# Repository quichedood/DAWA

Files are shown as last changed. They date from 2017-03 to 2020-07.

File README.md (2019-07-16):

New version here : https://github.com/quichedood/DAWA-6.1

# DAWA - Data Acquisition With Arduino
French official website project : http://dawa.panik-po.com/
DAWA-V4

DAWA is an Arduino datalogger (and laptimer) shield for your motorbike.
It records 10 times per seconds in a CSV file lots of information.

# What information is logged ?
* __Raw data acquisition__ : On Triumph bikes and many others, ECU values can be directly read (I personnaly use : RPM, SPEED, GEAR POSITION, THROTTLE and BRAKE state)
* __Environement values__ : A 9-axis sensor (BNO055) is used to store G-forces and I hope soon, roll and pitch
* __Position values__ : A UBLOX 10Hz GPS chip gets realtime coordinates
* __Infrared temperatures__ : You can plug up to 4 infrared temperature sensors (tyres or ground t° for example)
* __Analog inputs__ : You can measure up to 6 analog inputs (suspension sensors for exemple)

# Where is it logged ?
Everything is stored on a micro SD card.  
10 times per seconds, a new line is created in a CSV file. This line contains every data values separated by a semicolon.  
Current values are displayed in realtime on the OLED screen attached.

# Could it be used as a laptimer ?
YES ! Since v4 and the integration of a 10Hz GPS chip, laptimer functions are available.

# How does it work ?
I couldn't make it easier !  
Press the button start recording, press again stop recording :)  
One CSV file is created on each new record.

# What about laptimer functions
A little bit more difficult, you have to put a file named "TRACKS.CSV" on the sdcard.  
This file will contain track name and finishline coordinates, one line per track :  
`<trackname>;<finishline lat. A>;<finishline lon. A>;<finishline lat. B>;<finishline lon. B>`  
`CAROLE;489799930;25224350;489800230;25226330`  
To keep precision, latitude and longitude should be converted to integers (multiply by 10 000 000).  
When start recording the closer track is automatically chosen.

# You said Bluetooth ?
Bluetooth connection is usefull in these 2 cases :
- You just finish your track session and want to know lap times / best lap
- Before using DAWA, some parameters could be adjusted, use the bluetooth console to setup them !

I'm using "Serial Bluetooth Terminal" on Androïd. Connect and type "help" to view all available commands

# What's next  
* __Laptimer split time__ : Add split time management

# Known bugs
* __Lean angle__ : Seems easy but in fact very complicated to obtain good values without drift

# Repository Contents
* /Arduino - The .ino file you need to put in the Arduino M0
* /Documentation - Some brief explanations about this shield (french - not translated)
* /Eagle Libraries - All Eagle parts I use in my schematics
* /Eagle Sources - Eagle files of this project
* /Gerber Sources - Last Gerber files, used to produce PCB
* /Partslist - A detailed BOM list

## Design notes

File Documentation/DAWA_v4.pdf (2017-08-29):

Pourquoi ce montage ?

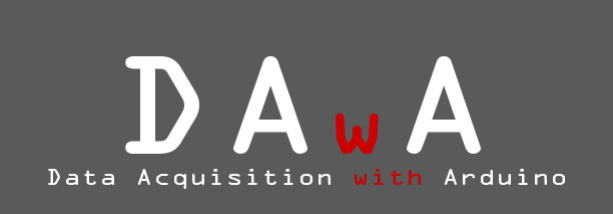
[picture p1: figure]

J’ai créé ce montage afin de pouvoir incruster dans mes vidéos différentes données comme par exemple le régime moteur ou encore l’inclinaison de la moto.

Certaines de ces informations peuvent être récupérées via des montages qui se branchent directement sur la prise OBD de la moto (prise diagnostic). L’implémentation est certes plus simple mais malheureusement sur nos motos, la version du protocole OBD utilisée est souvent ancienne et ne permet pas une lecture de plusieurs informations à une fréquence élevée. L’affichage est donc saccadé.

Pour ceux que ça intéresse, le très complet Freematics (http://freematics.com).

A qui est-il destiné ?

A tous les pistards équipés de motos Triumph. Ceux qui n’ont pas de Triumph mais qui sont intéressés, contactez-moi, on pourra étudier ça ensemble.

Comment ça marche ?

2 éléments font partis de ce projet :

- Un Arduino M0
C’est une carte électronique programmable que l’on trouve dans le commerce. C’est sur cette dernière que l’on trouve « l’intelligence » : le µprocesseur. Il peut être simplement programmé avec le code que je fournis via un câble USB relié au PC.
- Ma carte additionnelle
Cette carte additionnelle s'assemble avec l’Arduino M0, elle permet de faire l’interface avec la moto.

Quelles sont les données récupérées ?

Les données suivantes sont récupérées à une fréquence de 10Hz (10 fois par seconde) :
- Position de la poignée de gaz (de 0 à 100%)
- Activation de la poignée de frein (oui/non)
- Rapport engagé (N, 1, 2, 3, 4, 5, 6)
- Régime moteur (en tr/min)
- Inclinaison de la moto (tangage/roulis en degrés) – Problème de drift – code à corriger
- Température ambiante (en degrés)
- Coordonnées GPS de la moto
- Chronométrage (temps au tour)

Toutes ces données sont enregistrées sur la carte SD.

Comment ça se branche ?

2 branchements sont nécessaires :
- L’alimentation électrique, à brancher directement sur la batterie de la moto
- Le connecteur chargé de récupérer les données (5 fils) :
- Tr/min moteur (sur le calculateur)
- Vitesse moteur (sur le calculateur)
- Rapport engagé (sur le calculateur)
- Position de la poignée de gaz (sur le calculateur)
- Activation de la poignée de frein (sur le feu stop)

Comment l’utiliser ?

Très simplement, avant chaque session, un appui long sur le bouton permet d’activer l’enregistrement. Une fois la session terminée, un second appui long arrête l’enregistrement.

Le bouton est lumineux, son clignotement permet de s’assurer que l’enregistrement est bien en cours. Les données enregistrées sur la carte SD sont directement lisibles depuis un PC (fichier texte).

Le chronométrage fonctionne automatiquement du moment que les coordonnées GPS de la ligne d’arrivée du circuit sont saisis dans un fichier nommé « TRACKS.csv » présent à la racine de la carte SD. Le circuit le plus proche dans la liste sera automatiquement sélectionné.

Comment exploiter ces données ?

Différents logiciels existent sur le marché pour incruster des données sur une vidéo. Personnellement j’utilise Race Render (http://www.racerender.com).

Peut-on acheter ce montage tout fait ?

Je peux vous l’assembler oui, il faut compter environ 70€. (C’est +/- le prix de revient, je ne fais pas de marge) Cela comprend :
- Le montage DAWA (sans boitier)
- Un câble de 1m avec le bouton lumineux
- Un câble de 1m à relier sur les broches du calculateur
- L’antenne GPS
- L’Arduino M0

Soit à peu de choses près :

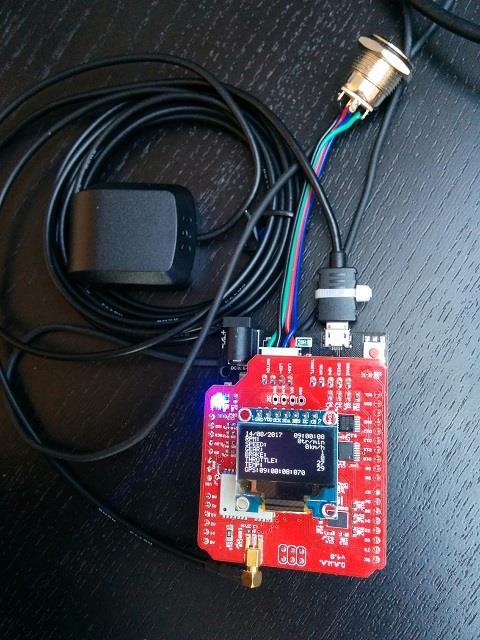
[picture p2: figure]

Il ne vous manquera plus qu’une carte micro SD et une pile plate CR1220

Des mises à jour sont prévues ?

Niveau matériel, je pense avoir enfin une version aboutie.
Un connecteur est tout de même présent au cas où l’on souhaite intégrer de nouveaux composants (protocole I2C).

Niveau programmation logiciel, c’est +/- sans limite donc pourquoi pas rajouter, comme certains me l’on demandé, des entrées pour les capteurs de position des suspensions ?

Néanmoins, la correction d’éventuels bugs est possible, il suffira de reprogrammer l’Arduino M0. Un PC et un câble USB vous suffiront !

Q&A

Q : J’ai déjà un Arduino M0, je peux l’utiliser ?
R : Bien sûr, rien de plus standard

Q : Est-ce que ce montage permet de me chronométrer ?
R : Oui depuis la version 4 ! Comparé à l’Alfano de référence les chronos sont pratiquement identiques. Les partiels ne sont pas gérés mais avec quelques lignes de code c’est largement faisable !

Q : Est-ce que ce montage fonctionne sur toutes les motos ?
R : Oui et non. Certaines motos (très) récentes commencent à utiliser des faisceaux multiplexés du coup impossible de récupérer chaque donnée sur un fil bien distinct. Généralisé dans l’automobile, BMW s’y essaie sur leurs motos pour les autres constructeurs j’ai un doute.
Sur les motos de marque autre que Triumph il faudra peut-être adapter quelques bricoles, à étudier. Néanmoins, la partie chronométrage ne s’appuie que sur la puce GPS donc fonctionnera sur toutes les motos.

Q : Est-ce garanti, y’a-t-il un support ?
R : Officiellement non, ça reste du « fait maison ». Après je réponds aux emails

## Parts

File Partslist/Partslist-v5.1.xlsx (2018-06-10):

Qty | Retailer | Value | Ref | Device | Package
1 | Mouser |  | CR1220 | 12mm 3V lithium coin cell
1 | Aliexpress |  |  | 12v connector
1 | Mouser |  | ADC128D818 | ADC | SOP65P640X120-16N
1 | Aliexpress |  |  | Arduino M0 (Robodyn)
1 | Aliexpress | 100pF |  | Capacitor | 0603
1 | Aliexpress | 10µF |  | Capacitor | 0603
1 | Aliexpress | 1µF |  | Capacitor | 0603
1 | Aliexpress | 4.7µF |  | Capacitor | 0603
2 | Aliexpress | 22pF |  | Capacitor | 0603
11 | Aliexpress | 0.1µF |  | Capacitor | 0603
1 | Mouser | 47pF | GRM1885C1H470JA01D | Capacitor | 0603
1 | Aliexpress |  | CD4050 | CMOS Hex Buffer/Converters | SOP65P640X120-16N
3 | Aliexpress |  | P82B96D | DUAL BIDIRECTIONAL BUS BUFFER | SOIC127P600X175-8N
1 | Aliexpress |  |  | GPS Antenna
1 | Aliexpress |  |  | GPS connector | MMCX STRAIGHT, EDGE MOUNT JACK- 50 OHM
1 | Aliexpress |  | UBLOX NEO-7M | GPS module
1 | Aliexpress |  |  | HM-11 (Bluetooth module) | JNHuaMao HM-11 Bluetooth 4.0 Transceiver
1 | Mouser | 27nH | LQG18HN27NJ00D | Inductor | 0603
2 | Aliexpress |  | MLX90614 ESF-BCC | Infrared temp. Sensor
1 | Mouser |  | BN055 | Intelligent 9-axis absolute orientation sensor | LGA-28_3.80X5.20/0.5
2 | Aliexpress |  |  | JST XH Connector (3 pins/F)
1 | Aliexpress |  |  | JST XH Connector (4 pins/F)
3 | Aliexpress |  |  | JST XH Connector (5 pins/F)
2 | Aliexpress |  |  | JST XH Connector (SMD/3 pins/M)
1 | Aliexpress |  |  | JST XH Connector (SMD/4 pins/M)
3 | Aliexpress |  |  | JST XH Connector (SMD/5 pins/M)
1 | Aliexpress |  |  | LED | 1206
1 | Aliexpress |  |  | Lithium coin cell 3v
1 | Aliexpress |  | DM3AT-SF-PEJM5 | Micro SD connector (SMD/push/push) | DM3AT-SF-PEJM5
1 | Aliexpress |  |  | OLED screen
2 | Mouser |  | TLV2374IPWR | OPERATIONAL AMPLIFIERS | SOP65P640X120-14N
1 | Mouser | 32.768kHz | CM7V-T1A | OSCILLATOR
1 | N/A |  |  | PCB
1 | Aliexpress |  |  | Pin header 1X32 (M)
1 | Mouser |  |  | Pin header 1X7 (F)
1 | Aliexpress |  |  | Pin header 2X3 (F)
1 | Aliexpress |  |  | Power button
1 | Mouser |  | CD40106BPW | QUADRUPLE LEVEL SHIFTER | SOP65P640X120-14N
1 | Aliexpress | 1kohm |  | Resistor | 0603
1 | Aliexpress | 200kohm |  | Resistor | 0603
1 | Aliexpress | 27kohm |  | Resistor | 0603
2 | Aliexpress | 220ohm |  | Resistor | 0603
8 | Aliexpress | 4.7kohm |  | Resistor | 0603
5 | Aliexpress | 10kohm |  | Resistor | 0603
1 | Mouser | 10ohm |  | Resistor | 1206
2 | Amazon |  |  | RJ45 (1m/2m)
3 | Aliexpress |  |  | RJ45 female socket
1 | Mouser |  | 24AA02E48 | Serial EEPROM | SOT23-5L
1 | Mouser |  | 74AHC1G125 | TRI-STATE SINGLE BUSS BUFFER | SOT23-5
1 | Mouser |  | PCA9306D | VOLTAGE-LEVEL TRANSLATOR | SOP50P310X90-8N
2 | Aliexpress |  |  | Wire cable (2m) - 4 cores
2 | Aliexpress |  |  | Wire cable (2m) - 5 cores

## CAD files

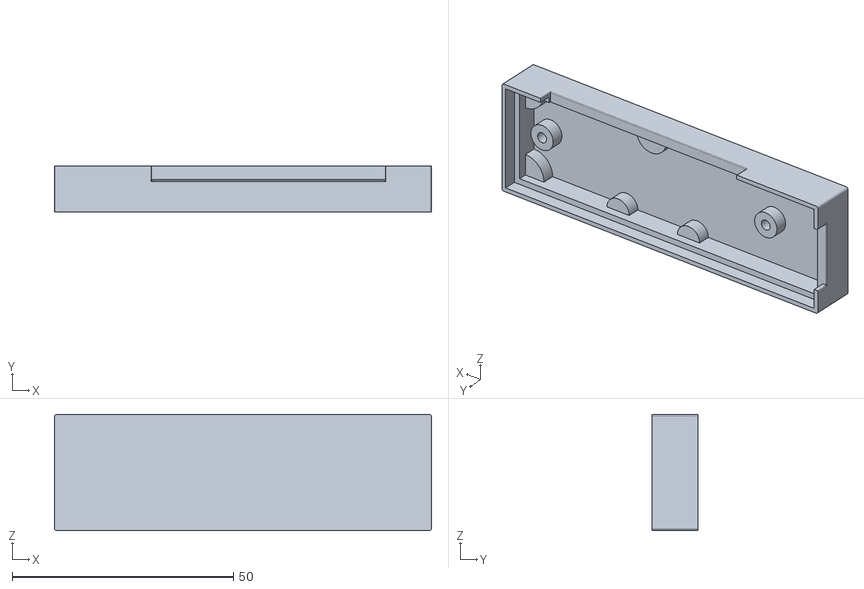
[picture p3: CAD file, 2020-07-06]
3D Case/MLX-SWITCH-PART1.stl
85.2 x 10.4 x 26.3

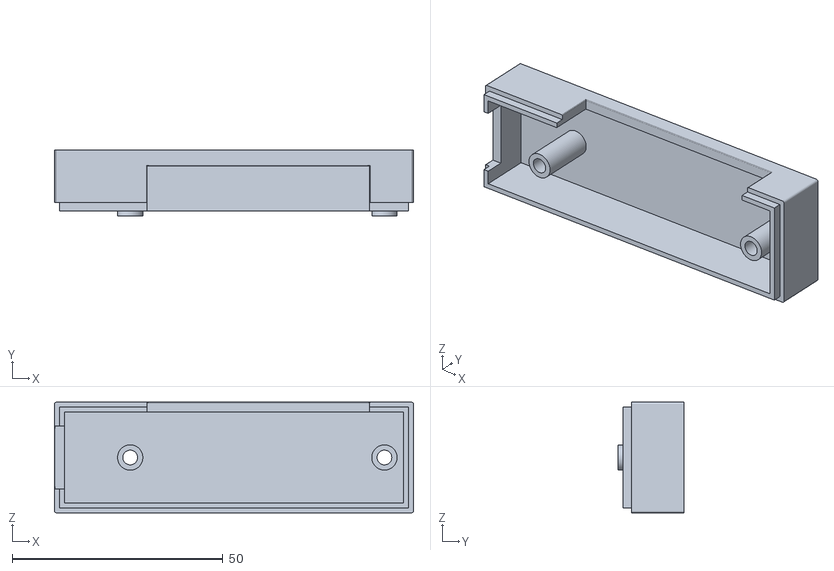
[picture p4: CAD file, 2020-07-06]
3D Case/MLX-SWITCH-PART2.stl
85.2 x 15.6 x 26.3

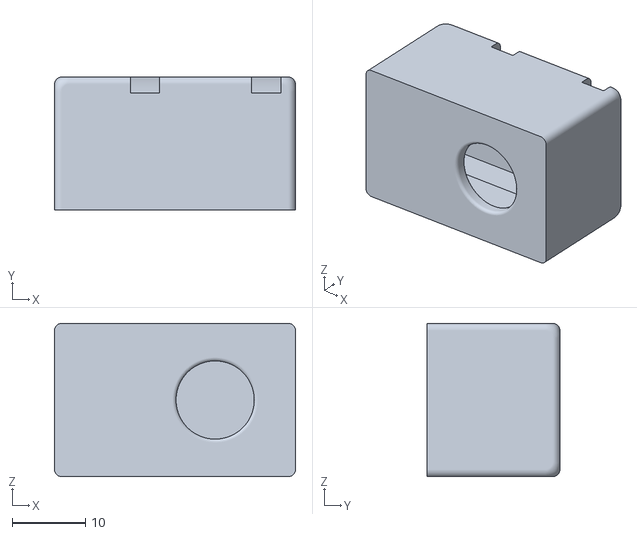
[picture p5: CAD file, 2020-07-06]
3D Case/MLX-PART1.stl
33.0 x 18.2 x 21.0

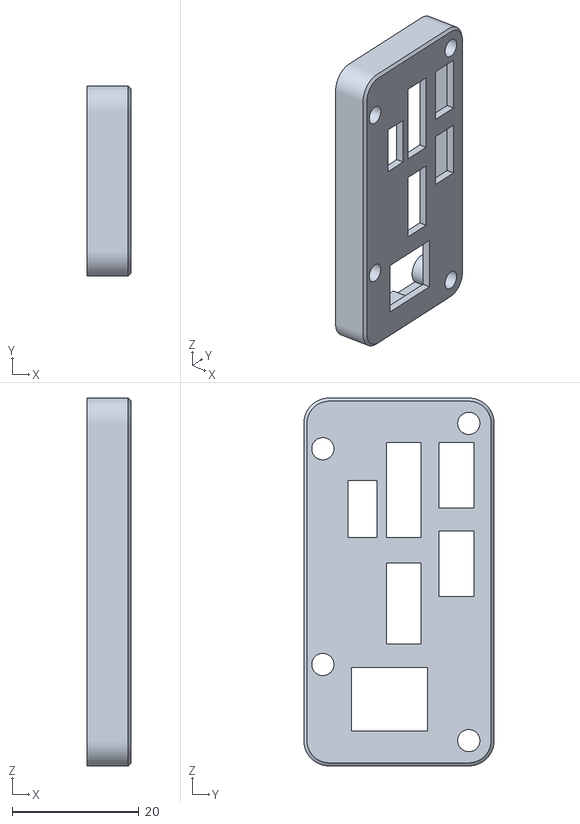
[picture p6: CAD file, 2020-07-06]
3D Case/DAWA-CASE-PART2.stl
7.00 x 30.0 x 58.0

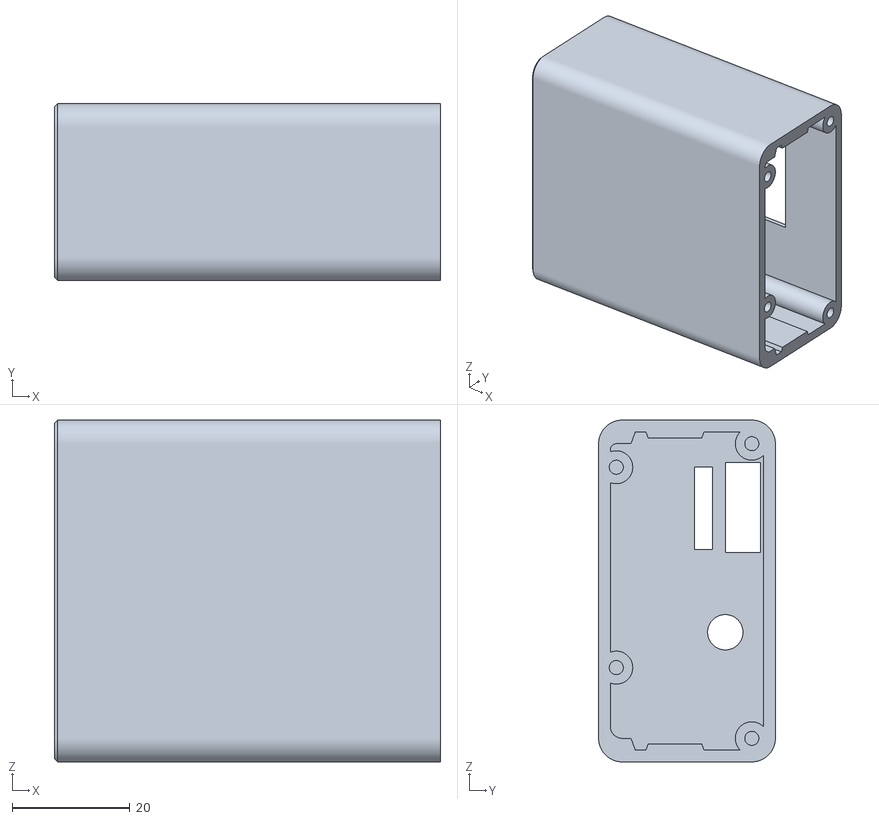
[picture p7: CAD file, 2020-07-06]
3D Case/DAWA-CASE-PART1.stl
65.5 x 30.0 x 58.0

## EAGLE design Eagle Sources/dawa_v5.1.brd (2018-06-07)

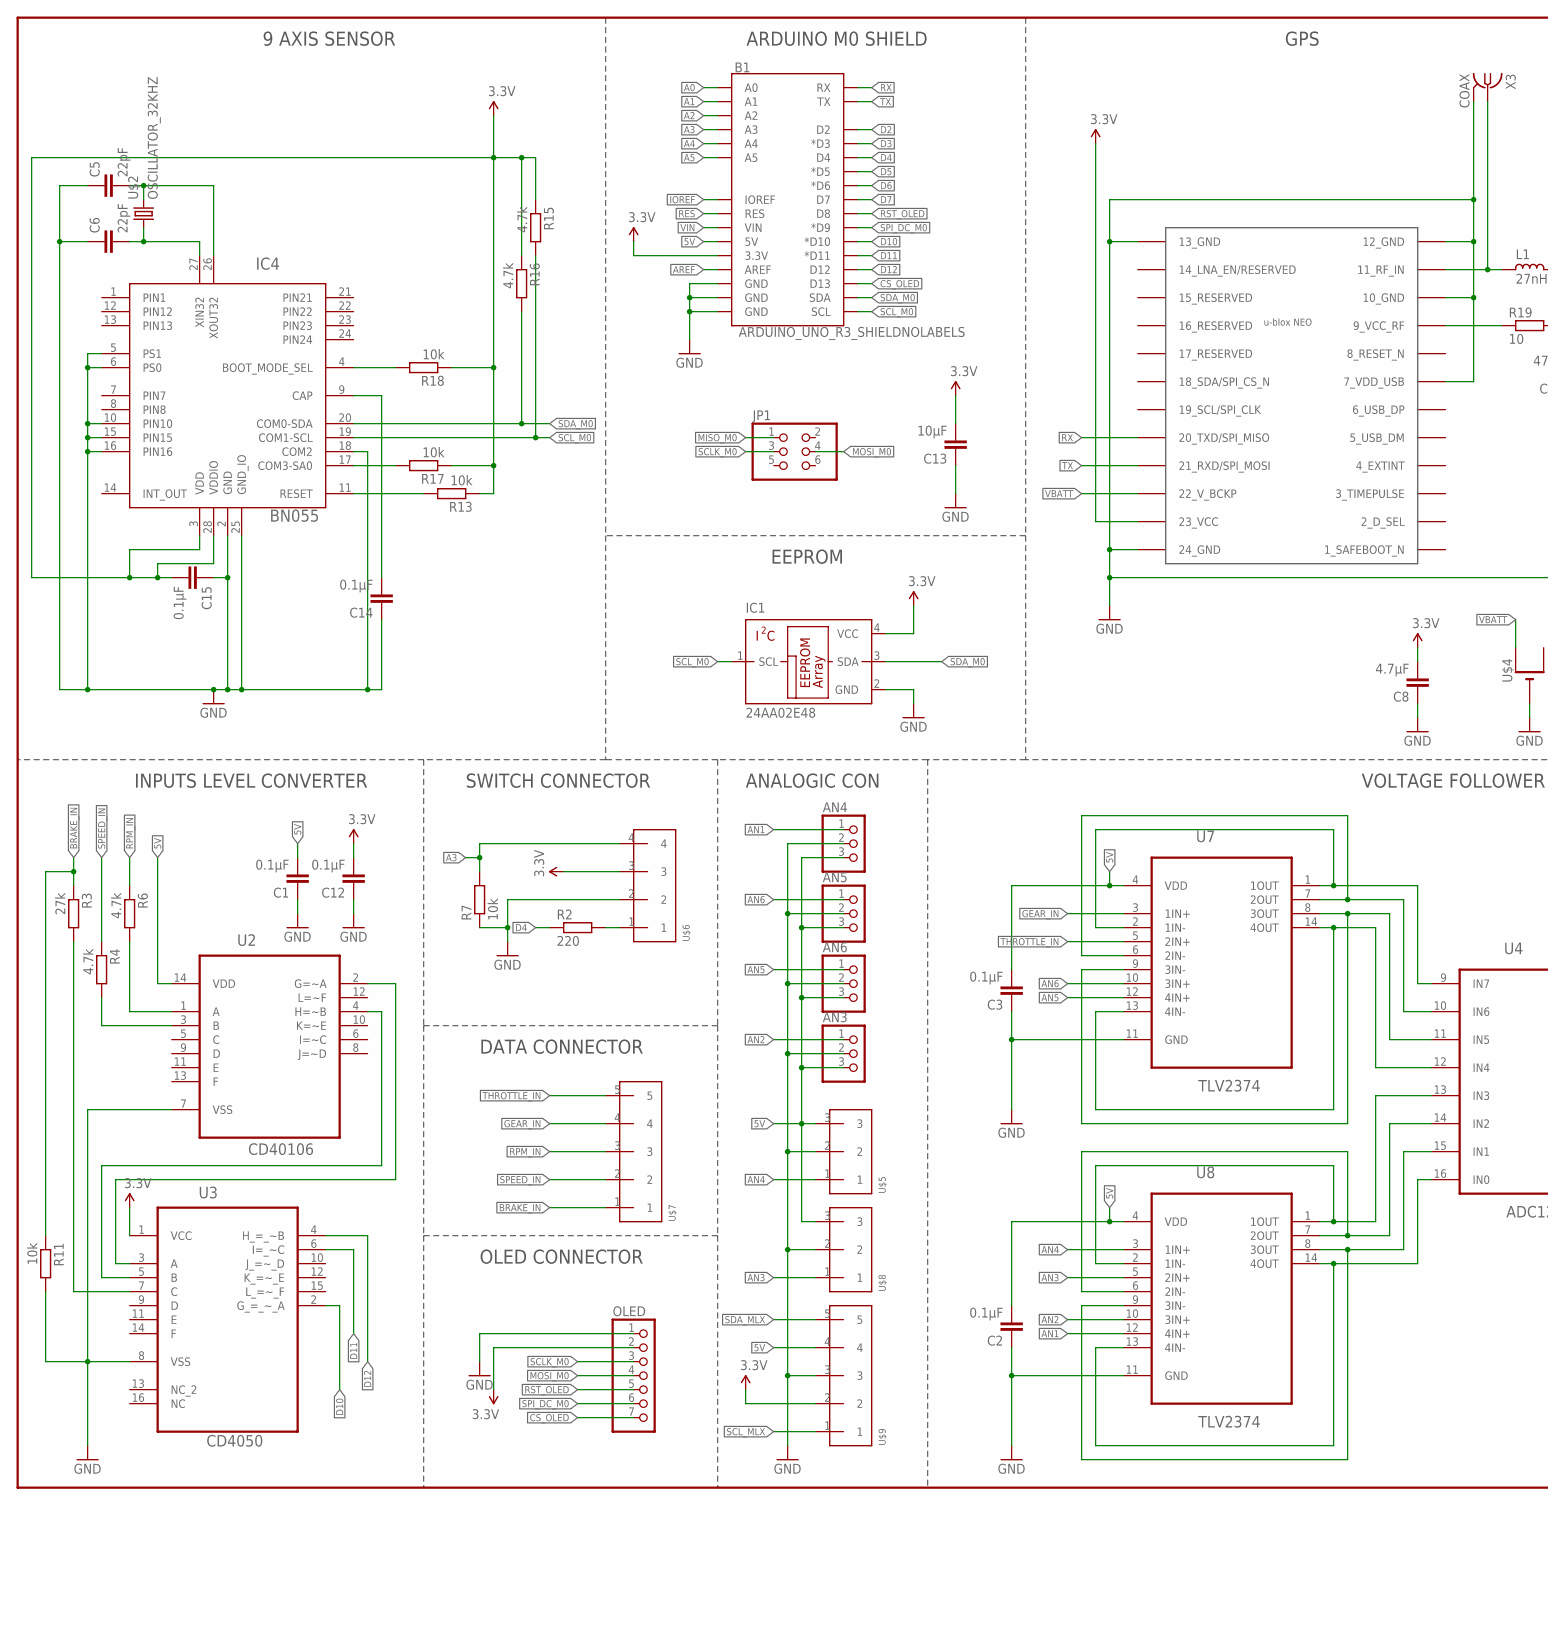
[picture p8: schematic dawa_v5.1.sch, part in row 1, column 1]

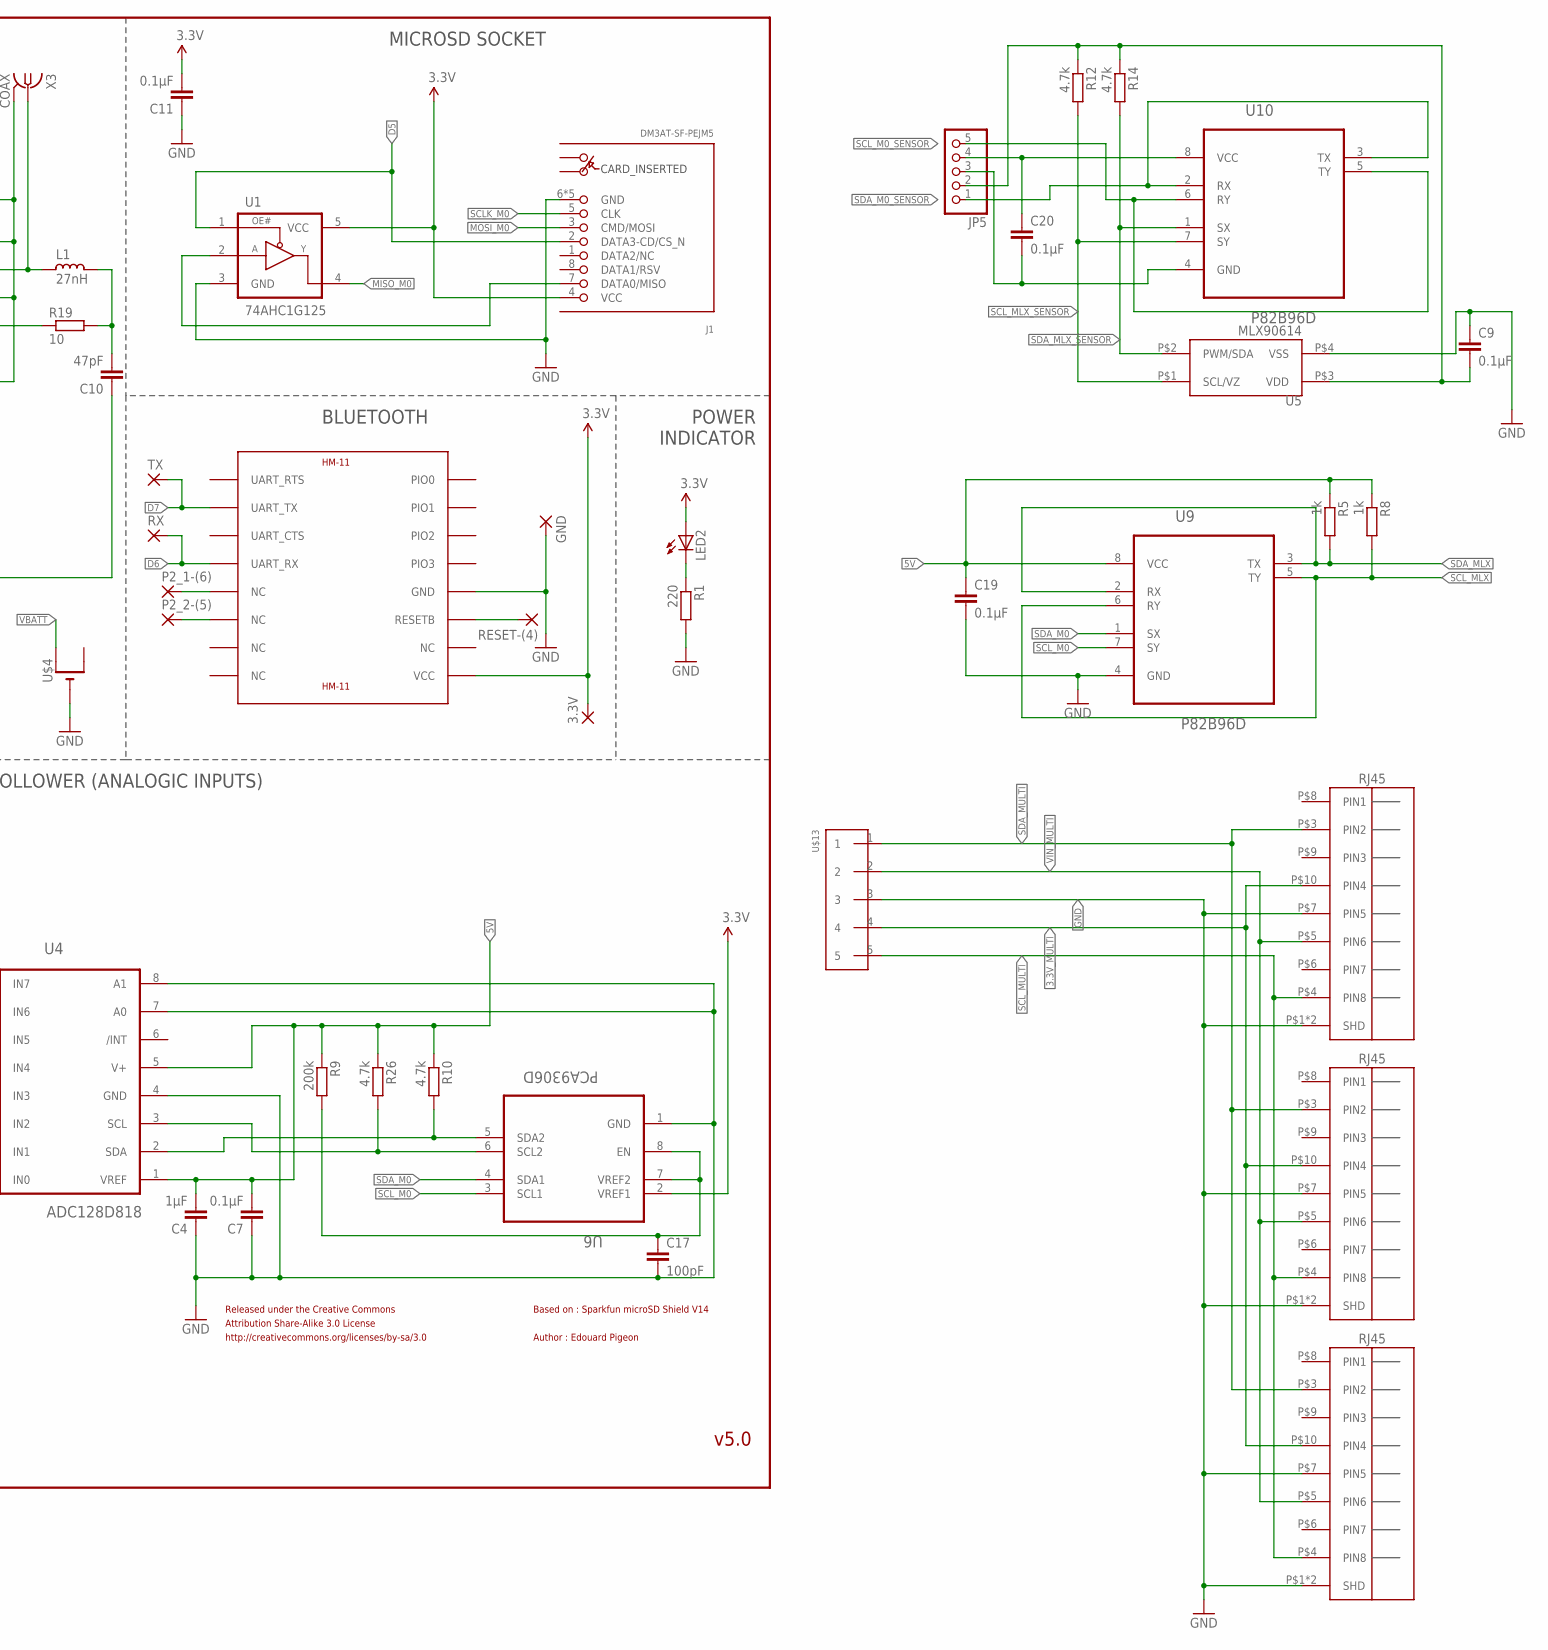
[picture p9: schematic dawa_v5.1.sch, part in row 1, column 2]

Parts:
3.3V: WIREPADSMD1,27-254; SMD1,27-2,54
AN3, AN4, AN5, AN6: PINHD-1X3; 1X03
B1: ARDUINO_UNO_R3_SHIELDNOLABELS; UNO_R3_SHIELD_NOLABELS
C1, C2, C3, C7, C9, C11, C12, C14, C15, C19, C20: 0.1µF; C0603
C4: 1µF; C0603
C5, C6: 22pF; C0603
C8: 4.7µF; C0603
C10: 47pF; C0603
C13: 10µF; C0603
C17: 100pF; C0603
GND: WIREPADSMD1,27-254; SMD1,27-2,54
IC1: 24AA02E48; SOT23-5L
IC4: BN055; LGA-28_3.80X5.20/0.5
J1: DM3AT-SF-PEJM5
JP1: PINHD-2X3; 2X03
JP5: PINHD-1X5; 1X05
L1: 27nH; L0603
LED2: LEDCHIPLED_1206; CHIPLED_1206
OLED: PINHD-1X7; 1X07
P2_1-(6), P2_2-(5): WIREPADSMD1,27-254; SMD1,27-2,54
R1, R2: 220; R0603
R3: 27k; R0603
R4, R6, R10, R12, R14, R15, R16, R26: 4.7k; R0603
R5, R8: 1k; R0603
R7, R11, R13, R17, R18: 10k; R0603
R9: 200k; R0603
R19: 10; M1206
RESET-(4): WIREPADSMD1,27-254; SMD1,27-2,54
RX: WIREPADSMD1,27-254; SMD1,27-2,54
TX: WIREPADSMD1,27-254; SMD1,27-2,54
U1: 74AHC1G125; SOT23-5
U2: CD40106; SOP65P640X120-14N
U3: CD4050; SOP65P640X120-16N
U4: ADC128D818; SOP65P640X120-16N
U5: MLX90614; TO-39
U6: PCA9306D; SOP50P310X90-8N
U7, U8: TLV2374; SOP65P640X120-14N
U9, U10: P82B96D; SOIC127P600X175-8N
U$1: HM-11
U$2: OSCILLATOR_32KHZ; OSCILLATOR_SMD
U$3: NEO-M8
U$4: CR1220SMT; CR1220-SMD
U$5, U$8: 3_PIN_JST-XH-SMD
U$6: 4_PIN_JST-XH-SMD
U$7, U$9, U$13: 5_PIN_JST-XH-SMD
U$10, U$11, U$12: RJ45
X3: COAX; MMCX-J-P-X-ST-EM1-MKT

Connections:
3.3V: 3.3V.1, B1.3.3V, C8.2, C11.2, C12.2, C13.2, C15.2, IC1.4 (VCC), IC4.3 (VDD), IC4.28 (VDDIO), J1.4 (VCC), LED2.A, OLED.2, R13.1, R15.1, R16.1, R17.1, R18.1, U1.5 (VCC), U3.1 (VCC), U6.2 (VREF1), U$1.VCC, U$3.23 (23_VCC), U$6.3, U$9.2
3.3V_MULTI: U$10.P$10 (PIN4), U$11.P$10 (PIN4), U$12.P$10 (PIN4), U$13.4
5V: AN3.3, AN4.3, AN5.3, AN6.3, B1.5V, C1.2, C2.2, C3.2, C4.2, C7.2, C19.1, R5.1, R8.1, R9.1, R10.1, R26.1, U2.14 (VDD), U4.1 (VREF), U4.5 (V+), U7.4 (VDD), U8.4 (VDD), U9.8 (VCC), U$5.3, U$8.3, U$9.4
A0: B1.A0
A1: B1.A1
A2: B1.A2
A3: B1.A3, R7.2, U$6.4
A4: B1.A4
A5: B1.A5
AN1: AN4.1, U8.12 (4IN+)
AN2: AN3.1, U8.10 (3IN+)
AN3: U8.5 (2IN+), U$8.1
AN4: U8.3 (1IN+), U$5.1
AN5: AN6.1, U7.12 (4IN+)
AN6: AN5.1, U7.10 (3IN+)
AREF: B1.AREF
BRAKE_IN: R3.1, R11.1, U$7.1
CS_OLED: B1.D13, OLED.7
D2: B1.D2
D3: B1.D3 (*D3)
D4: B1.D4, R2.1
D5: B1.D5 (*D5), J1.2 (DATA3-CD/CS_N), U1.1 (OE#)
D6: B1.D6 (*D6), RX.1, U$1.UART_RX
D7: B1.D7, TX.1, U$1.UART_TX
D10: B1.D10 (*D10), U3.2 (G_=_~_A)
D11: B1.D11 (*D11), U3.6 (I=_~C)
D12: B1.D12, U3.4 (H_=_~B)
GEAR_IN: U7.3 (1IN+), U$7.4
GND: AN3.2, AN4.2, AN5.2, AN6.2, B1.GND@0 (GND), B1.GND@1 (GND), B1.GND@2 (GND), C1.1, C2.1, C3.1, C4.1, C5.1, C6.1, C7.1, C8.1, C9.1, C10.1, C11.1, C12.1, C13.1, C14.1, C15.1, C17.2, C19.2, GND.1, IC1.2 (GND), IC4.2 (GND), IC4.5 (PS1), IC4.6 (PS0), IC4.10 (PIN10), IC4.15 (PIN15), IC4.16 (PIN16), IC4.18 (COM2), IC4.25 (GND_IO), J1.6 (GND), J1.MOUNT0 (GND), J1.MOUNT1 (GND), J1.MOUNT2 (GND), J1.MOUNT3 (GND), OLED.1, R1.2, R7.1, R11.2, U1.3 (GND), U2.7 (VSS), U3.8 (VSS), U4.4 (GND), U4.7 (A0), U4.8 (A1), U5.P$4 (VSS), U6.1 (GND), U7.11 (GND), U8.11 (GND), U9.4 (GND), U$1.GND, U$3.7 (7_VDD_USB), U$3.10 (10_GND), U$3.12 (12_GND), U$3.13 (13_GND), U$3.24 (24_GND), U$4.-, U$5.2, U$6.2, U$8.2, U$9.3, U$10.P$1 (SHD), U$10.P$2 (SHD), U$10.P$7 (PIN5), U$11.P$1 (SHD), U$11.P$2 (SHD), U$11.P$7 (PIN5), U$12.P$1 (SHD), U$12.P$2 (SHD), U$12.P$7 (PIN5), U$13.3, X3.2@1 (GND), X3.2@2 (GND), X3.2@3 (GND), X3.2@4 (GND)
IOREF: B1.IOREF
MISO_M0: JP1.1, U1.4 (Y)
MOSI_M0: J1.3 (CMD/MOSI), JP1.4, OLED.4
unnamed: R2.2, U$6.1
unnamed: R6.2, U2.1 (A)
unnamed: U2.2 (G=~A), U3.3 (A)
unnamed: R4.2, U2.3 (B)
unnamed: R3.2, U3.7 (C)
unnamed: LED2.C, R1.1
unnamed: IC4.11 (RESET), R13.2
unnamed: P2_1-(6).1, U$1.NC@5 (NC)
unnamed: RESET-(4).1, U$1.RESETB
unnamed: J1.7 (DATA0/MISO), U1.2 (A)
unnamed: C10.2, L1.1, R19.2
unnamed: U4.13 (IN3), U8.1 (1OUT), U8.2 (1IN-)
unnamed: C14.2, IC4.9 (CAP)
unnamed: IC4.4 (BOOT_MODE_SEL), R18.2
unnamed: C5.2, IC4.26 (XOUT32), U$2.2
unnamed: C6.2, IC4.27 (XIN32), U$2.1
unnamed: IC4.17 (COM3-SA0), R17.2
unnamed: P2_2-(5).1, U$1.NC@6 (NC)
unnamed: R19.1, U$3.9 (9_VCC_RF)
unnamed: L1.2, U$3.11 (11_RF_IN), X3.1
unnamed: U2.4 (H=~B), U3.5 (B)
unnamed: R26.2, U4.3 (SCL), U6.6 (SCL2)
unnamed: R10.2, U4.2 (SDA), U6.5 (SDA2)
unnamed: U4.9 (IN7), U7.1 (1OUT), U7.2 (1IN-)
unnamed: U4.10 (IN6), U7.6 (2IN-), U7.7 (2OUT)
unnamed: U4.11 (IN5), U7.8 (3OUT), U7.9 (3IN-)
unnamed: U4.12 (IN4), U7.13 (4IN-), U7.14 (4OUT)
unnamed: C17.1, R9.2, U6.7 (VREF2), U6.8 (EN)
unnamed: U4.14 (IN2), U8.6 (2IN-), U8.7 (2OUT)
unnamed: U4.15 (IN1), U8.8 (3OUT), U8.9 (3IN-)
unnamed: U4.16 (IN0), U8.13 (4IN-), U8.14 (4OUT)
unnamed: C20.1, JP5.4, U10.8 (VCC)
unnamed: C9.2, JP5.2, R12.1, R14.1, U5.P$3 (VDD)
unnamed: C20.2, JP5.3, U10.4 (GND)
RES: B1.RES
RPM_IN: R6.1, U$7.3
RST_OLED: B1.D8, OLED.5
RX: B1.RX, U$3.20 (20_TXD/SPI_MISO)
SCLK_M0: J1.5 (CLK), JP1.3, OLED.3
SCL_M0: B1.SCL, IC1.1 (SCL), IC4.19 (COM1-SCL), R15.2, U6.3 (SCL1), U9.7 (SY)
SCL_M0_SENSOR: JP5.5, U10.5 (TY), U10.6 (RY)
SCL_MLX: R8.2, U9.5 (TY), U9.6 (RY), U$9.1
SCL_MLX_SENSOR: R12.2, U5.P$1 (SCL/VZ), U10.7 (SY)
SCL_MULTI: U$10.P$4 (PIN8), U$11.P$4 (PIN8), U$12.P$4 (PIN8), U$13.5
SDA_M0: B1.SDA, IC1.3 (SDA), IC4.20 (COM0-SDA), R16.2, U6.4 (SDA1), U9.1 (SX)
SDA_M0_SENSOR: JP5.1, U10.2 (RX), U10.3 (TX)
SDA_MLX: R5.2, U9.2 (RX), U9.3 (TX), U$9.5
SDA_MLX_SENSOR: R14.2, U5.P$2 (PWM/SDA), U10.1 (SX)
SDA_MULTI: U$10.P$3 (PIN2), U$11.P$3 (PIN2), U$12.P$3 (PIN2), U$13.1
SPEED_IN: R4.1, U$7.2
SPI_DC_M0: B1.D9 (*D9), OLED.6
THROTTLE_IN: U7.5 (2IN+), U$7.5
TX: B1.TX, U$3.21 (21_RXD/SPI_MOSI)
VBATT: U$3.22 (22_V_BCKP), U$4.+$1 (+)
VIN: B1.VIN
VIN_MULTI: U$10.P$5 (PIN6), U$11.P$5 (PIN6), U$12.P$5 (PIN6), U$13.2

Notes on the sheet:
POWER INDICATOR
Released under the Creative Commons
v5.0
VOLTAGE FOLLOWER (ANALOGIC INPUTS)
MICROSD SOCKET
ARDUINO M0 SHIELD
BLUETOOTH
Attribution Share-Alike 3.0 License
http://creativecommons.org/licenses/by-sa/3.0
Based on : Sparkfun microSD Shield V14
Author : Edouard Pigeon
9 AXIS SENSOR
INPUTS LEVEL CONVERTER
OLED CONNECTOR
DATA CONNECTOR
EEPROM
SWITCH CONNECTOR
GPS
ANALOGIC CON

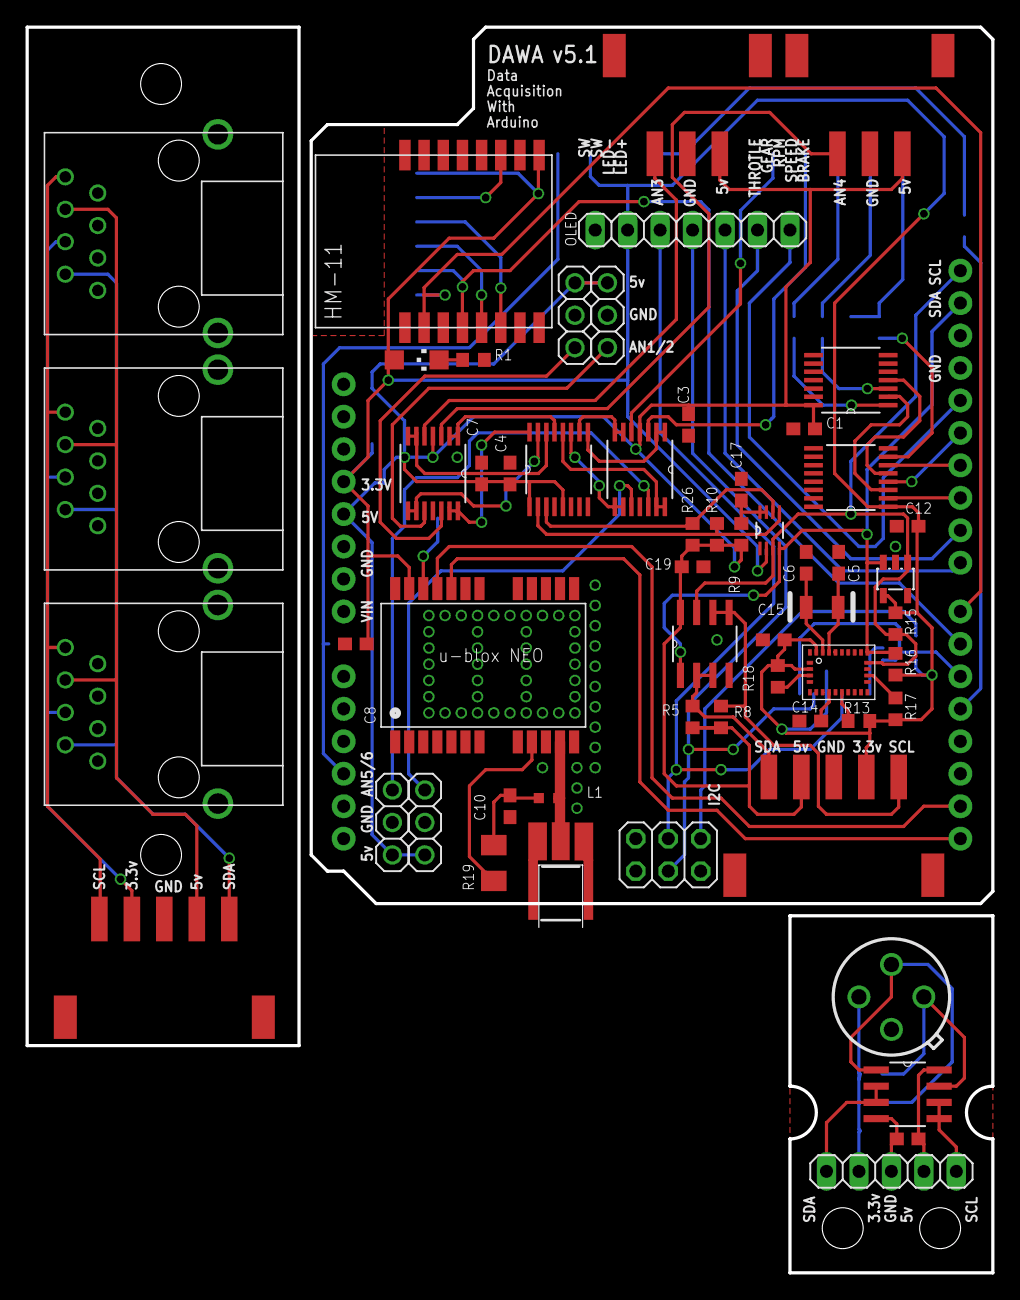
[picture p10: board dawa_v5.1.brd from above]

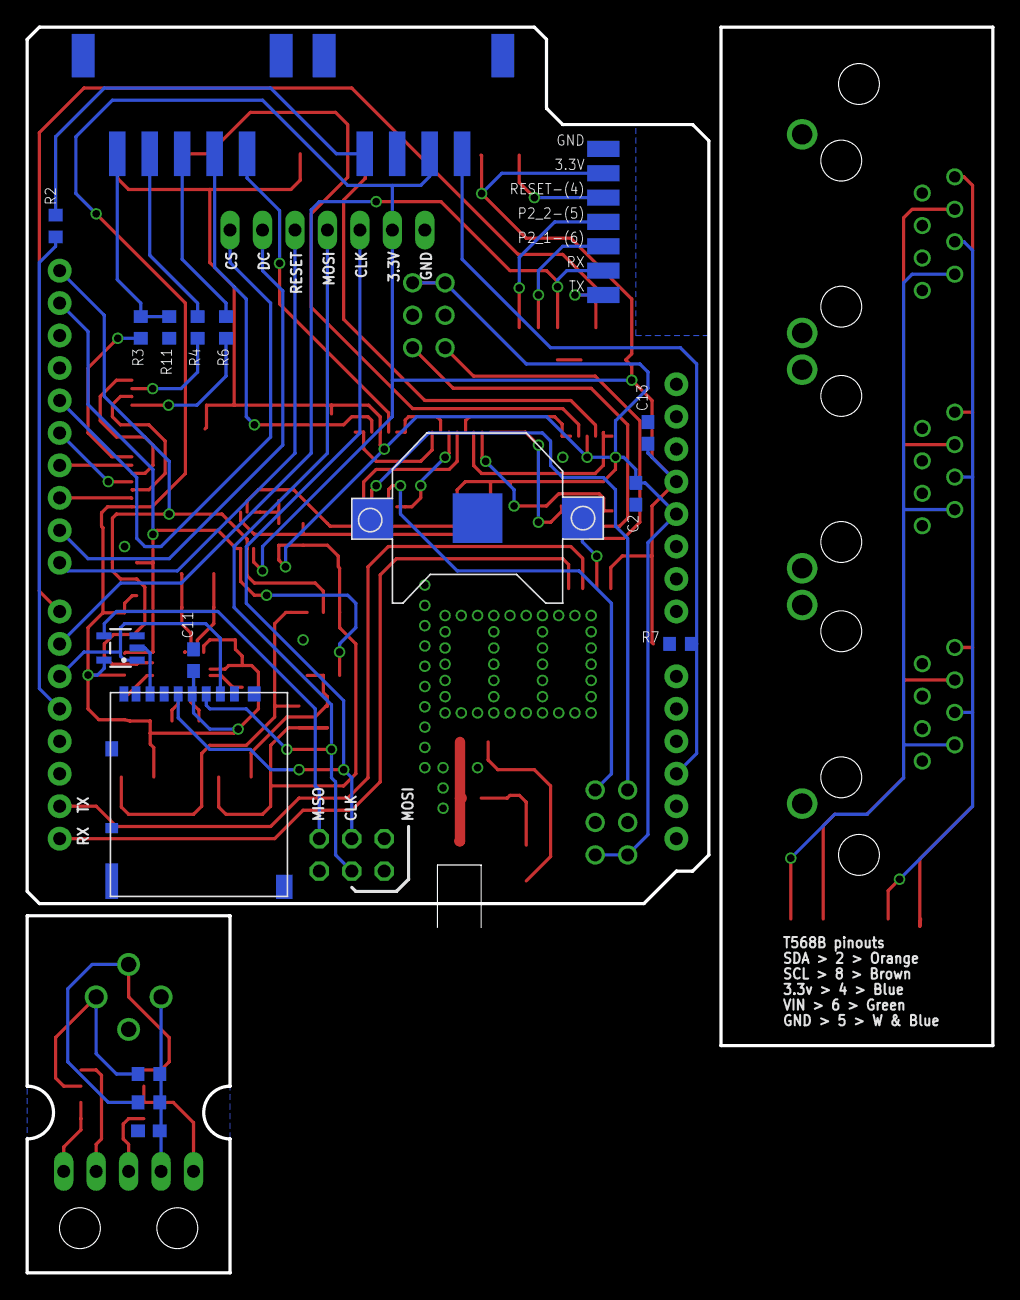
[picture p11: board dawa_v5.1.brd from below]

Board: 2 copper layers, 75.6 x 97.5 mm, 82 parts (24 on the bottom side), 77 nets.

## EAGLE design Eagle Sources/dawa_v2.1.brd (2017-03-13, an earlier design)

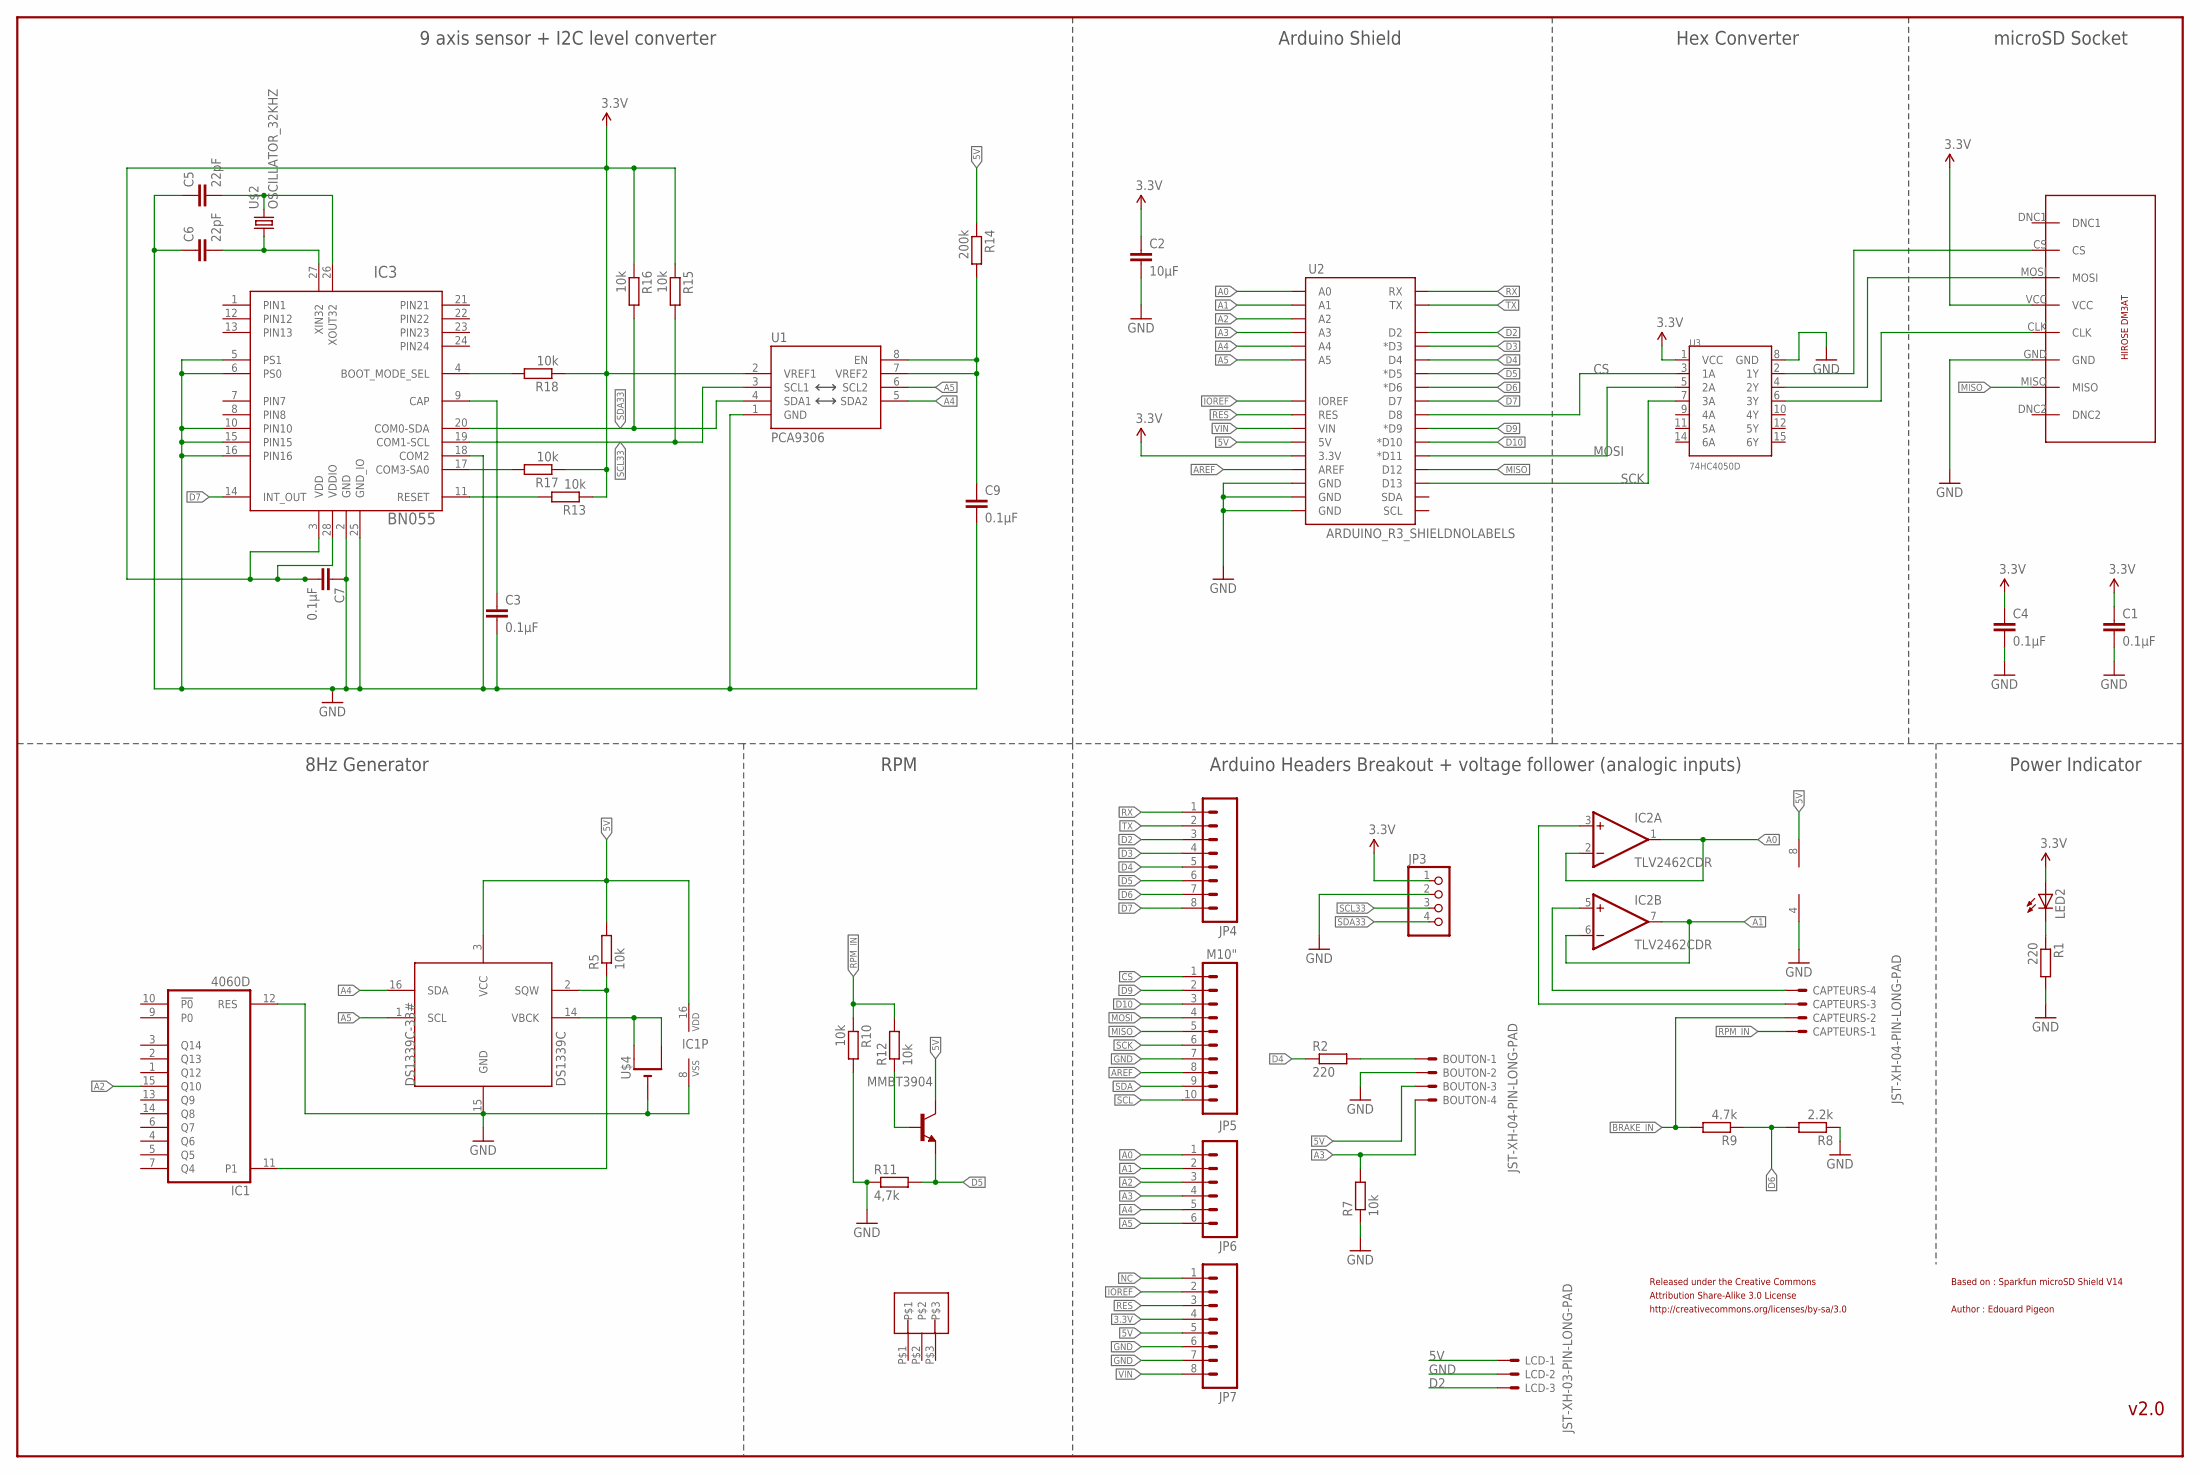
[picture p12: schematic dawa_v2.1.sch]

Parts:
BOUTON: JST-XH-04-PIN-LONG-PAD; JST-XH-04-PACKAGE-LONG-PAD
C1, C3, C4, C7, C9: 0.1µF; C1206
C2: 10µF; C1206
C5, C6: 22pF; C1206
CAPTEURS: JST-XH-04-PIN-LONG-PAD; JST-XH-04-PACKAGE-LONG-PAD
DS1339C-33#: DS1339C
IC1: 4060D; SO16
IC2: TLV2462CDR; SO08
IC3: BN055; LGA-28_3.80X5.20/0.5
JP3: PINHD-1X4; 1X04
JP4: M08; 1X08
JP5: M10"; 1X10
JP6: M06SIP; 1X06
JP7: M081X08; 1X08
LCD: JST-XH-03-PIN-LONG-PAD; JST-XH-03-PACKAGE-LONG-PAD
LED2: LEDCHIPLED_1206; CHIPLED_1206
MMBT3904: MMBT3904LT1-NPN-SOT23-BEC; SOT23-BEC
R1, R2: 220; M1206
R5, R7, R10, R12, R13, R15, R16, R17, R18: 10k; M1206
R8: 2.2k; M1206
R9: 4.7k; M1206
R11: 4,7k; M1206
R14: 200k; M1206
U1: PCA9306; PSOP-8
U2: ARDUINO_R3_SHIELDNOLABELS; UNO_R3_SHIELD_NOLABELS
U3: 74HC4050D; SO016
U$2: OSCILLATOR_32KHZ; OSCILLATOR_SMD
U$3: 3_PIN_JST-XH
U$4: CR1220SMT; CR1220-SMD
U$5: DM3AT

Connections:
3.3V: C1.1, C2.1, C4.1, C7.2, IC3.3 (VDD), IC3.28 (VDDIO), JP3.1, JP7.4, LED2.A, R13.1, R15.1, R16.1, R17.1, R18.1, U1.2 (VREF1), U2.3.3V, U3.1 (VCC), U$5.VCC
5V: BOUTON.3, DS1339C-33#.3 (VCC), IC1.16 (VDD), IC2.8 (V+), JP7.5, LCD.1, MMBT3904.C, R5.2, R14.1, U2.5V
A0: IC2.1 (OUT), IC2.2 (-IN), JP6.1, U2.A0
A1: IC2.6 (-IN), IC2.7 (OUT), JP6.2, U2.A1
A2: IC1.15 (Q10), JP6.3, U2.A2
A3: BOUTON.4, JP6.4, R7.2, U2.A3
A4: DS1339C-33#.16 (SDA), JP6.5, U1.5 (SDA2), U2.A4
A5: DS1339C-33#.1 (SCL), JP6.6, U1.6 (SCL2), U2.A5
AREF: JP5.8, U2.AREF
BRAKE_IN: CAPTEURS.2, R9.2
CS: JP5.1, U2.D8, U3.3 (1A)
D2: JP4.3, LCD.3, U2.D2
D3: JP4.4, U2.D3 (*D3)
D4: JP4.5, R2.1, U2.D4
D5: JP4.6, MMBT3904.E, R11.2, U2.D5 (*D5)
D6: JP4.7, R8.2, R9.1, U2.D6 (*D6)
D7: IC3.14 (INT_OUT), JP4.8, U2.D7
D9: JP5.2, U2.D9 (*D9)
D10: JP5.3, U2.D10 (*D10)
GND: BOUTON.2, C1.2, C2.2, C3.2, C4.2, C5.1, C6.1, C7.1, C9.2, DS1339C-33#.15 (GND), IC1.8 (VSS), IC1.12 (RES), IC2.4 (V-), IC3.2 (GND), IC3.5 (PS1), IC3.6 (PS0), IC3.10 (PIN10), IC3.15 (PIN15), IC3.16 (PIN16), IC3.18 (COM2), IC3.25 (GND_IO), JP3.2, JP5.7, JP7.6, JP7.7, LCD.2, R1.2, R7.1, R8.1, R10.2, R11.1, U1.1 (GND), U2.GND@0 (GND), U2.GND@1 (GND), U2.GND@2 (GND), U3.8 (GND), U$4.-, U$5.GND
IOREF: JP7.2, U2.IOREF
MISO: JP5.5, U2.D12, U$5.MISO
MOSI: JP5.4, U2.D11 (*D11), U3.5 (2A)
unnamed: BOUTON.1, R2.2
unnamed: U3.4 (2Y), U$5.MOSI
unnamed: DS1339C-33#.14 (VBCK), U$4.+$1 (+), U$4.+$2 (+1)
unnamed: U3.6 (3Y), U$5.CLK
unnamed: LED2.C, R1.1
unnamed: IC3.11 (RESET), R13.2
unnamed: CAPTEURS.4, IC2.5 (+IN)
unnamed: CAPTEURS.3, IC2.3 (+IN)
unnamed: C9.1, R14.2, U1.7 (VREF2), U1.8 (EN)
unnamed: C3.1, IC3.9 (CAP)
unnamed: IC3.4 (BOOT_MODE_SEL), R18.2
unnamed: C5.2, IC3.26 (XOUT32), U$2.2
unnamed: C6.2, IC3.27 (XIN32), U$2.1
unnamed: IC3.17 (COM3-SA0), R17.2
unnamed: DS1339C-33#.2 (SQW), IC1.11 (P1), R5.1
unnamed: MMBT3904.B, R12.1
unnamed: U3.2 (1Y), U$5.CS
NC: JP7.1
RES: JP7.3, U2.RES
RPM_IN: CAPTEURS.1, R10.1, R12.2
RX: JP4.1, U2.RX
SCK: JP5.6, U2.D13, U3.7 (3A)
SCL: JP5.10
SCL33: IC3.19 (COM1-SCL), JP3.3, R15.2, U1.3 (SCL1)
SDA: JP5.9
SDA33: IC3.20 (COM0-SDA), JP3.4, R16.2, U1.4 (SDA1)
TX: JP4.2, U2.TX
VIN: JP7.8, U2.VIN

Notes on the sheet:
Power Indicator
Released under the Creative Commons
v2.0
Arduino Headers Breakout + voltage follower (analogic inputs)
microSD Socket
Hex Converter
Arduino Shield
8Hz Generator
RPM
Attribution Share-Alike 3.0 License
http://creativecommons.org/licenses/by-sa/3.0
Based on : Sparkfun microSD Shield V14
Author : Edouard Pigeon
9 axis sensor + I2C level converter

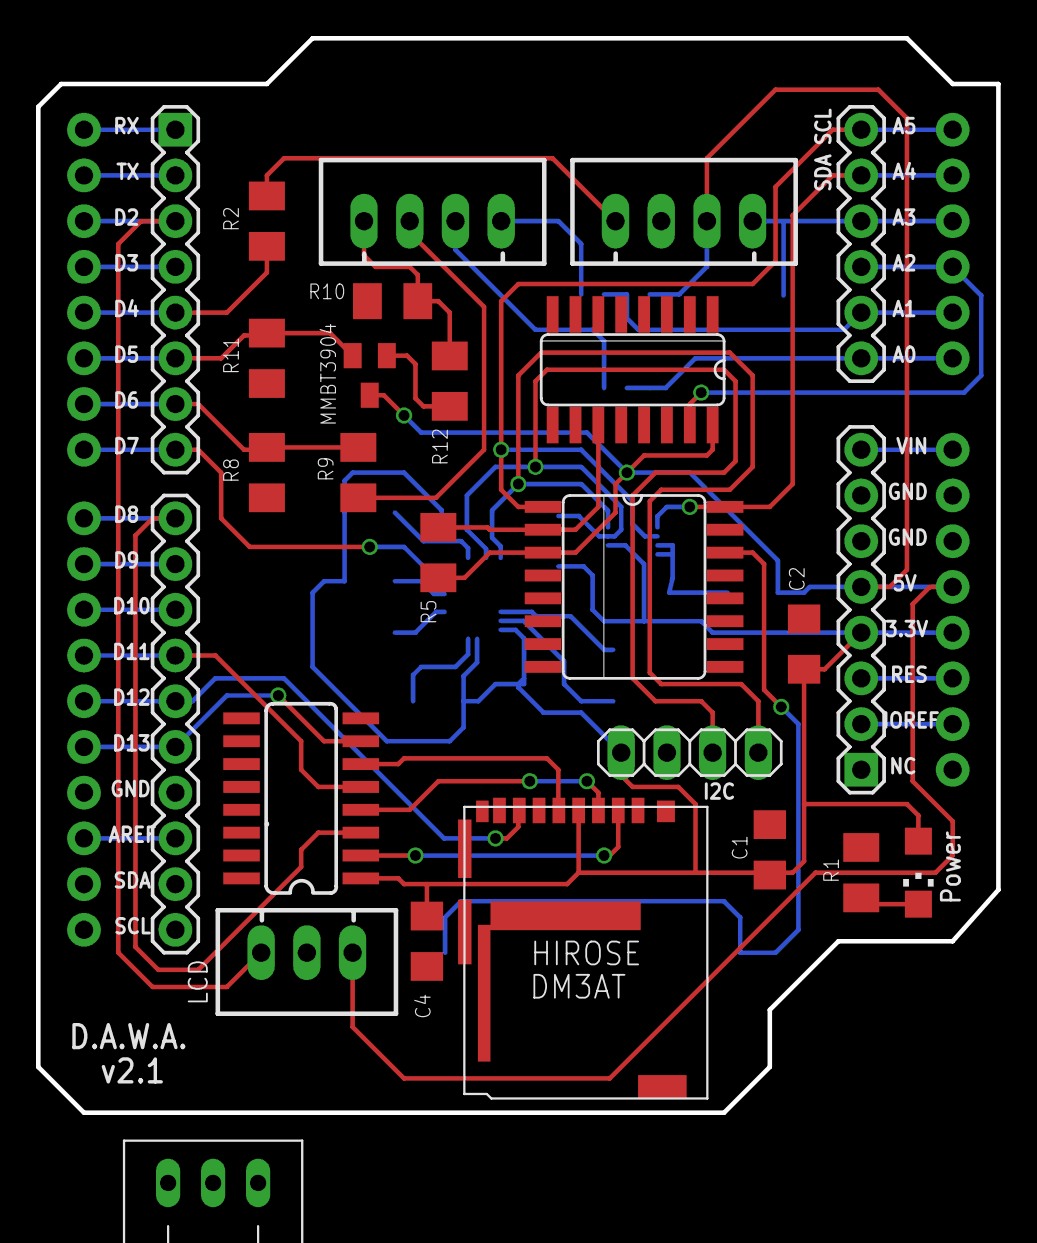
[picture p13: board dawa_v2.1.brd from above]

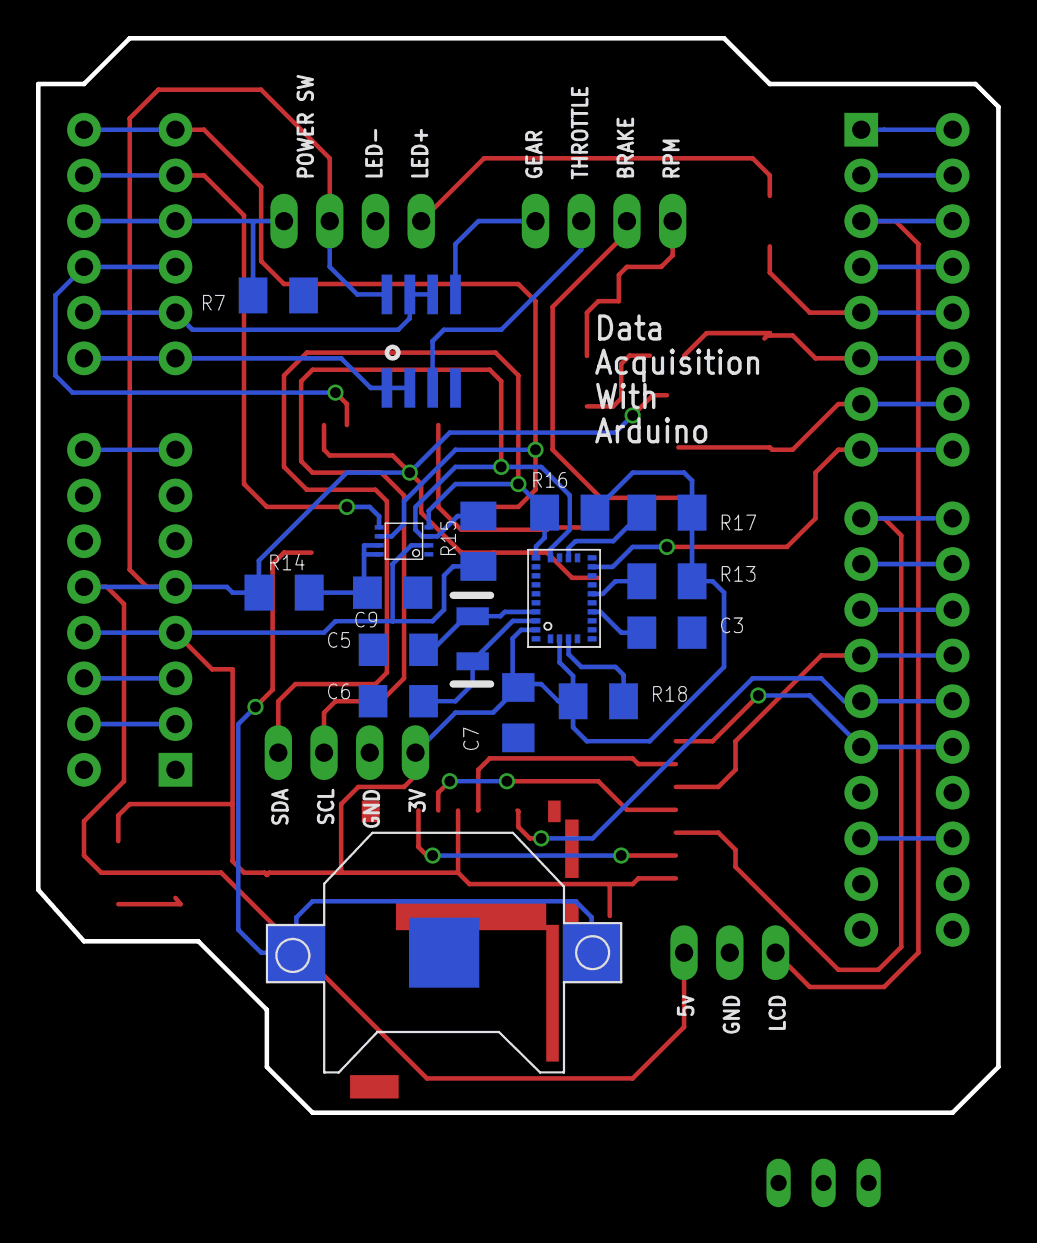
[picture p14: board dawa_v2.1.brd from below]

Board: 2 copper layers, 53.3 x 59.7 mm, 44 parts (17 on the bottom side), 48 nets.

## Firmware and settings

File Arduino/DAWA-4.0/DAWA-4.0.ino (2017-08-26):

/*
   DAWA 4.0 (Arduino M0)
   Triumph motorbikes laptimer/datalogger
   Edouard PIGEON - 2017
*/

// Librairies
#include <SPI.h>

/*
   NeoGPS library
   https://github.com/SlashDevin/NeoGPS
*/
#include <NMEAGPS.h>
HardwareSerial & gps_port = Serial5;
#define DEBUG_PORT SERIAL_PORT_USBVIRTUAL // Debug to USB serial console
static NMEAGPS  gps;
static gps_fix  fix_data;
static gps_fix  fix_data_prev;

/*
   thomasfredericks/Bounce2 library
   https://github.com/thomasfredericks/Bounce2
*/
#include <Bounce2.h>
Bounce debouncer = Bounce();

/*
   Greiman/SdFat library
   https://github.com/greiman/SdFat
*/
#include <SdFat.h>

/*
   Maxim DS13xx library
   https://github.com/adafruit/RTClib
*/
#include <RTClib.h>

/*
   Modified dtostrf function defnition
   http://forum.arduino.cc/index.php?topic=368720.0
*/
#include <dtostrf.h>

/*
   External EEPROM library

   extEEPROM.c >
   //REMOVE l.98 :
   //TWBR = ( (F_CPU / twiFreq) - 16) / 2;

   //REPLACE l.98 :
   //sercom3.disableWIRE();                         // Disable the I2C bus
   //SERCOM3->I2CM.BAUD.bit.BAUD = SystemCoreClock / ( 2 * 400000) - 1 ;   // // Set the I2C SCL frequency to 400kHz
   //sercom3.enableWIRE();                          // Restart the I2C bus
   // https://forum.arduino.cc/index.php?topic=347425.0

   extEEPROM.h >
   ADD l.63 :
   #define BUFFER_LENGTH 64 // Add var here because no more defined in wire.h (SAMD21's buffer = 64)
*/
#include <extEEPROM.h> // Arduino External EEPROM Library v3.0 (Official Github : https://github.com/JChristensen/extEEPROM)
extEEPROM eep(kbits_2, 1, 8); // I2C Address 0x50

/*
   Modification of the EEPROMAnything library that allows you to read and write any data structure or array to and from the external EEPROM
   https://forum.arduino.cc/index.php?topic=358648.0
*/
#include <EEPROMAnything2.h> // Enable object read/write on EEPROM

/*
   LCD library
   SPI ASCII OLED : https://github.com/greiman/SSD1306Ascii
*/
// SPI ASCII OLED libraries
#include "SSD1306Ascii.h" // OLED LCD based on SSD1306 chip, ASCII only no graphics
#include "SSD1306AsciiSpi.h"
SSD1306AsciiSpi oled; // 128x64 LCD OLED
#define OLED_DC 9
#define OLED_CS 13

/*
   9-axis Bosch BNO055 Adafruit library
   https://github.com/adafruit/Adafruit_BNO055
*/
#include <Adafruit_BNO055.h> // Adafruit 9-axis BNO_055 lib
#include <Adafruit_Sensor.h>
Adafruit_BNO055 bno = Adafruit_BNO055(55, BNO055_ADDRESS_B); // USE_BNO055_ADDRESS_B = Adress 0x29 (COM3 pin set to 1)

/*
   Variable PINs I/O
*/
#define CSV_DELIM ';'
const float bikeRpmCoeff = 1.05; // Enable high RPM correction
const unsigned int maxTrackDistance = 5; // Autoselect nearer track (unit = km)
const uint8_t ledPin = 4; // D4
const uint8_t powerPin = A3; //A3
const uint8_t brakePin = 11; // D11
const uint8_t throttlePin = A0; // A0
const uint8_t gearPin = A1; // A1
const uint8_t sdCsPin = 7; // D7
const uint8_t oledResetPin = 8; // D8
const uint8_t timepulsePin = A2; //A2
const unsigned char ubxRate10Hz[] PROGMEM = {0x06, 0x08, 0x06, 0x00, 0x64, 0x00, 0x01, 0x00, 0x01, 0x00};
const unsigned char ubxTimepulse[] PROGMEM = {0x06, 0x31, 0x20, 0x00, 0x00, 0x01, 0x00, 0x00, 0x00, 0x00, 0x00, 0x00, 0x0A, 0x00, 0x00, 0x00, 0x01, 0x00, 0x00, 0x00, 0x00, 0x00, 0x00, 0x80, 0x00, 0x00, 0x00, 0x00, 0x00, 0x00, 0x00, 0x00, 0x29, 0x00, 0x00, 0x00};
//                                           |ID         |Lenght     |TP   |res  |res        |antCableD  |rfGrDelay  |freqPeriod             |freqPeriod lock        |Pulselenghtratio       |Pulselenghtratiolock   |UserConfigDelay        |Flags                 |

/*
   Vars
*/
unsigned long lastPinRead = 0;
unsigned long lastLCDupdate = 0;
unsigned long lastSdSync = 0;
unsigned long stopwatchStartTime = 0;
unsigned int elapsedTime = 0;
char trackName[16];
bool recordTrackData;
byte lapCounter = 0;
bool addFinishLog = 0;

// GPS
bool gpsDataReady = false;
float flineLat1, flineLon1, flineLat2, flineLon2 = 0;
float posCrossLat, posCrossLon;
float distanceKm;
float tToFl;

// Sensors
bool sensorsDataReady = false;
unsigned int bikeRpm;
unsigned int bikeSpeed;
unsigned int gearValue;
char gear = 'N';
byte gearNCheck = 0;
bool brake = false;
bool isRunning = false;
unsigned int throttle;

// RTC
RTC_DS1307 rtc;
char datetime[11];

// SD Card
SdFat sd;
File logFile;
File trackFile;
char filename[20];

// Display
char lcdString[20];
byte lcdLine = 0;

// 9-axis sensor
byte temperature; // Don't go out when freezing ;)
byte cal_sys, cal_gyro, cal_accel, cal_mag = 0;
adafruit_bno055_offsets_t calibrationData;
sensors_event_t event;
//byte *calibrationBuffer = (byte *) &calibrationData;

/*
   Triggered when initialization error (program stop and slow blinking led)
*/
void initerror() {
  delay(2000); // Pause 3 sec pour lecture infos LCD
  while (1) {
    digitalWrite(ledPin, digitalRead(ledPin) ^ 1); // Clignotement LED rapide (indique une erreur)
    delay(200);
  }
}

/*
   Send UBX commands to UBLOX GPS
*/
void sendUBX(const unsigned char *progmemBytes, size_t len) {
  gps_port.write(0xB5); // SYNC1
  gps_port.write(0x62); // SYNC2

  uint8_t a = 0, b = 0;
  while (len-- > 0) {
    uint8_t c = pgm_read_byte(progmemBytes++);
    a += c;
    b += a;
    gps_port.write(c);
  }
  gps_port.write(a); // CHECKSUM A
  gps_port.write(b); // CHECKSUM B
}

/*
   Read CSV file
   https://github.com/greiman/SdFat/blob/master/examples/ReadCsv/ReadCsv.ino

   Read a file one field at a time.
   file - File to read.
   str - Character array for the field.
   size - Size of str array.
   delim - csv delimiter.
   return - negative value for failure.
            delimiter, '\n' or zero(EOF) for success.
*/
int csvReadText(File* file, char* str, size_t size, char delim) {
  char ch;
  int rtn;
  size_t n = 0;
  while (true) {
    // check for EOF
    if (!file->available()) {
      rtn = 0;
      break;
    }
    if (file->read(&ch, 1) != 1) {
      // read error
      rtn = -1;
      break;
    }
    // Delete CR.
    if (ch == '\r') {
      continue;
    }
    if (ch == delim || ch == '\n') {
      rtn = ch;
      break;
    }
    if ((n + 1) >= size) {
      // string too long
      rtn = -2;
      n--;
      break;
    }
    str[n++] = ch;
  }
  str[n] = '\0';
  return rtn;
}

int csvReadUint32(File* file, uint32_t* num, char delim) {
  char buf[20];
  char* ptr;
  int rtn = csvReadText(file, buf, sizeof(buf), delim);
  if (rtn < 0) return rtn;
  *num = strtoul(buf, &ptr, 10);
  if (buf == ptr) return -3;
  while (isspace(*ptr)) ptr++;
  return *ptr == 0 ? rtn : -4;
}

int csvReadUint16(File* file, uint16_t* num, char delim) {
  uint32_t tmp;
  int rtn = csvReadUint32(file, &tmp, delim);
  if (rtn < 0) return rtn;
  if (tmp > UINT_MAX) return -5;
  *num = tmp;
  return rtn;
}

int csvReadDouble(File* file, double* num, char delim) {
  char buf[20];
  char* ptr;
  int rtn = csvReadText(file, buf, sizeof(buf), delim);
  if (rtn < 0) return rtn;
  *num = strtod(buf, &ptr);
  if (buf == ptr) return -3;
  while (isspace(*ptr)) ptr++;
  return *ptr == 0 ? rtn : -4;
}

int csvReadFloat(File* file, float* num, char delim) {
  double tmp;
  int rtn = csvReadDouble(file, &tmp, delim);
  if (rtn < 0)return rtn;
  // could test for too large.
  *num = tmp;
  return rtn;
}

/*
   Calculate 2 line segments intersection
*/
bool segIntersect(float pos_now_lat, float pos_now_lon, float pos_prev_lat, float pos_prev_lon, float &trackLat1, float &trackLon1, float &trackLat2, float &trackLon2, float &pos_cross_lat, float &pos_cross_lon) {
  float denom, s_numer, t_numer, t, track_pos_x, track_pos_y, pos_x, pos_y, trackLon, trackLat;
  bool denomPositive;

  /*DEBUG_PORT.print("TR:");
    DEBUG_PORT.print(trackLat1, 8);
    DEBUG_PORT.print(";");
    DEBUG_PORT.print(trackLon1, 8);
    DEBUG_PORT.print(";");
    DEBUG_PORT.print(trackLat2, 8);
    DEBUG_PORT.print(";");
    DEBUG_PORT.println(trackLon2, 8);
    DEBUG_PORT.print("POS:");
    DEBUG_PORT.print(pos_now_lat, 8);
    DEBUG_PORT.print(";");
    DEBUG_PORT.print(pos_now_lon, 8);
    DEBUG_PORT.print(";");
    DEBUG_PORT.print(pos_prev_lat, 8);
    DEBUG_PORT.print(";");
    DEBUG_PORT.println(pos_prev_lon, 8);*/

  trackLon = trackLon2 - trackLon1;
  trackLat = trackLat2 - trackLat1;
  pos_x = pos_now_lon - pos_prev_lon;
  pos_y = pos_now_lat - pos_prev_lat;

  denom = trackLon * pos_y - pos_x * trackLat;
  if (denom == 0) {
    return 0; // Collinear
  }

  if (denom > 0) {
    denomPositive = true;
  } else {
    denomPositive = false;
  }

  track_pos_x = trackLon1 - pos_prev_lon;
  track_pos_y = trackLat1 - pos_prev_lat;

  s_numer = trackLon * track_pos_y - trackLat * track_pos_x;
  if ((s_numer < 0) == denomPositive) {
    return 0; // No collision
  }

  t_numer = pos_x * track_pos_y - pos_y * track_pos_x;
  if ((t_numer < 0) == denomPositive) {
    return 0; // No collision
  }

  if (((s_numer > denom) == denomPositive) || ((t_numer > denom) == denomPositive)) {
    return 0; // No collision
  }

  // Collision detected
  t = t_numer / denom;
  pos_cross_lat = trackLat1 + (t * trackLat);
  pos_cross_lon = trackLon1 + (t * trackLon);

  return 1;
}

/*
   Calculate distance between 2 GPS coords (unit = km, precision = meters) - haversine formula
*/
float gpsDistance(float lat1, float lon1, float lat2, float lon2) {
  float p = 0.017453292519943295; // (Pi / 180)
  float a = 0.5000 - cos((lat2 - lat1) * p) / 2 + cos(lat1 * p) * cos(lat2 * p) * (1 - cos((lon2 - lon1) * p)) / 2;
  return 12742 * asin(sqrt(a)); // 12742 = 2x earth radius
}
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
void loop() {
  // Update the Bounce instance :
  debouncer.update();

  // ON/OFF
  if (debouncer.rose()) { // long press on power button
    if (isRunning) { // If stopwatch is running ...
      isRunning = false; // ... we stop recording
      digitalWrite(ledPin, 0); // LED off
      logFile.close(); // Close file on SDcard
      oled.clear();
    } else {
      oled.clear();
      oled.println("Running ...");

      // Select nearer track
      recordTrackData = false;
      trackFile = sd.open("TRACKS.csv", FILE_READ);
      if (trackFile) {
        while (trackFile.available()) {
          csvReadText(&trackFile, trackName, sizeof(trackName), CSV_DELIM); // One line per track : "CAROLE;48.979993;2.522435;48.980023;2.522633" (<trackname>;<strartline_a_lat>;<strartline_a_lon>;<strartline_b_lat>;<strartline_b_lon>)
          csvReadFloat(&trackFile, &flineLat1, CSV_DELIM);                  // Points A & B should be at the left and at the right of the finishline (a few meters)
          csvReadFloat(&trackFile, &flineLon1, CSV_DELIM);
          csvReadFloat(&trackFile, &flineLat2, CSV_DELIM);
          csvReadFloat(&trackFile, &flineLon2, CSV_DELIM);

          distanceKm = gpsDistance(fix_data.latitude(), fix_data.longitude(), flineLat1, flineLon1); // Get the nearer track from us
          if (distanceKm <= maxTrackDistance) {
            recordTrackData = true;
            oled.print(trackName);
            oled.print(" (");
            oled.print(distanceKm, 1);
            oled.println("km)");
            break;
          }
        }
        trackFile.close();
      }
      if (recordTrackData == false) {
        oled.println("No tracks file !");
      }

      // We adjust RTC clock with GPS datetime (UTC only)
      if (fix_data.valid.time) {
        rtc.adjust(DateTime(fix_data.dateTime.year, fix_data.dateTime.month, fix_data.dateTime.date, fix_data.dateTime.hours, fix_data.dateTime.minutes, fix_data.dateTime.seconds));
      }
      DateTime now = rtc.now(); // Get date now

      // Create datafile
      sprintf(filename, "%02u%02u%02u-%02u%02u%02u.txt", now.year(), now.month(), now.day(), now.hour(), now.minute(), now.second());
      if (logFile.open(filename, O_CREAT | O_WRITE | O_EXCL)) {
        logFile.println(F("lap;timestamp;brake;throttle;gear;rpm;speed;speedgps;heading;roll;pitch;temp;lat;lon"));
      } else {
        initerror();
      }

      // Define stopwatch start time
      isRunning = true; // ... we start recording
      lapCounter = 0;
      stopwatchStartTime = millis();
    }
  }

  // Get GPS frames through serial port (this is CRITICAL, data could be sent at any moment by the GPS so main loop should be executed in a minimum of time)
  if (gps.available(gps_port)) { // && gpsDataReady == false ?
    fix_data_prev = fix_data; // Memorize previous values before next GPS fix
    fix_data = gps.read();
    gpsDataReady = true;
  }

  // Every ~100ms (10Hz), we get all values (RPM, Speed, brake, gear, 9-axis data)
  elapsedTime = millis() - lastPinRead;
  if (elapsedTime >= 100) {
    lastPinRead = millis(); // Reset last pin read

    // Read RPM & SPEED counters
    REG_TCC0_CTRLBSET = TCC_CTRLBSET_CMD_READSYNC;  // Trigger a read synchronization on the COUNT register
    while (TCC0->SYNCBUSY.bit.CTRLB);               // Wait for the CTRLB register write synchronization
    while (TCC0->SYNCBUSY.bit.COUNT);               // Wait for the COUNT register read sychronization
    bikeSpeed = REG_TCC0_COUNT;                     // Read TCNT0 register (timer0 counter)
    REG_TCC0_COUNT = 0x0000;                        // Clear timer's COUNT value
    while (TCC0->SYNCBUSY.bit.COUNT);               // Wait for synchronization

    REG_TCC1_CTRLBSET = TCC_CTRLBSET_CMD_READSYNC;  // Trigger a read synchronization on the COUNT register
    while (TCC1->SYNCBUSY.bit.CTRLB);               // Wait for the CTRLB register write synchronization
    while (TCC1->SYNCBUSY.bit.COUNT);               // Wait for the COUNT register read sychronization
    bikeRpm = REG_TCC1_COUNT;                       // Read TCNT1 register (timer1 counter)
    REG_TCC1_COUNT = 0x0000;                        // Clear timer's COUNT value
    while (TCC1->SYNCBUSY.bit.COUNT);               // Wait for synchronization

    brake = digitalRead(brakePin); // Read "brakePin" (pin is plugged on the "+" of the stop light)
    throttle = min(((analogRead(throttlePin) / 10) * 1.23), 100); // Read voltage on "throttlePin"
    gearValue = analogRead(gearPin); // Read voltage on "gearPin" : every gear output a specific voltage (raw data measured on Daytona 675 : 314, 520, 660, 787, 888, 975, 1023 (N))
    bikeRpm = bikeRpm * bikeRpmCoeff * 600 * 100 / elapsedTime / 22; // Ratio between pulse and rpm (22 > flywheel has 22 teeth ### 600 > with check every 100ms, RPM is by minute) ### (* 100 / elapsedTime) > if we read counter @101ms or 102ms values should be adjusted
    bikeSpeed = bikeSpeed * 100 / elapsedTime; // Speed ratio is 1 so no maths ### (* 100 / elapsedTime) > if we read counter @101ms or 102ms values should be adjusted

    // Get 9-axis sensor data
    bno.getEvent(&event);

    // Gear selected
    if (gearValue <= 433) {
      gear = '1';
    }
    if (gearValue > 433 && gearValue <= 590) {
      gear = '2';
    }
    if (gearValue > 590 && gearValue <= 723) {
      gear = '3';
    }
    if (gearValue > 723 && gearValue <= 837) {
      gear = '4';
    }
    if (gearValue > 837 && gearValue <= 931) {
      gear = '5';
    }
    if (gearValue > 931 && gearValue <= 997) {
      gear = '6';
    }
    if (gearValue > 998) { // "N" = 1023
      if (gearNCheck > 3) { // We test 3 times to prevent displaying "N" between 2 gears
        gear = 'N';
      } else {
        gearNCheck++;
      }
    } else {
      gearNCheck = 0;
    }
    sensorsDataReady = true;
  }

  // Sync file on SDcard every 30sec to avoid dataloss on power failure
  if (isRunning && (millis() - lastSdSync > 30000)) {
    lastSdSync = millis();
    logFile.sync();
  }

  /*
    Displaying on LCD
    Everything is optional
  */
  if (millis() - lastLCDupdate > 1000) {
    // Get other data (not time critical, so every 1 sec)
    temperature = bno.getTemp(); // Temperature
    //bno.getCalibration(&cal_sys, &cal_gyro, &cal_accel, &cal_mag); // Calibration status

    lastLCDupdate = millis();
    if (isRunning) {
      // Blinking LED (user knows it's running), no other data is printed on LCD because it's time consumming and we'll loose some GPS frame
      digitalWrite(ledPin, digitalRead(ledPin) ^ 1);
    } else {
      DateTime now = rtc.now();
      oled.setCursor(0, 0);
      oled.print(now.day());
      oled.print("/");
      oled.print(now.month());
      oled.print("/");
      oled.print(now.year());
      oled.print(" ");
      oled.print(now.hour());
      oled.print(":");
      oled.print(now.minute());
      oled.print(":");
      oled.println(now.second());
      oled.print("RPM:       ");
      oled.println(bikeRpm);
      oled.print("SPEED:     ");
      oled.println(bikeSpeed);
      oled.print("GEAR:      ");
      oled.println(gear);
      oled.print("BRAKE:     ");
      oled.println(brake);
      oled.print("THROTTLE:  ");
      oled.println(throttle);
      //oled.print("LAP:     ");
      //oled.println(lapCounter);

      /*49.004837036,2.239411116
        49.004840851,2.239416122
        49.004866,2.239351
        49.004815,2.239474
        if (segIntersect(49.004837036,2.239411116, 49.004840851,2.239416122, 49.004866, 2.239351, 49.004815,2.239474, posCrossLat, posCrossLon)) {
        oled.println("CROSS");

        } else {
        oled.println("NOT CROSS");
        }*/

      oled.print("TEMP:      ");
      oled.println(temperature);
      oled.print("GPS:");
      oled.print(fix_data.dateTime);
      oled.print(".");
      oled.print(fix_data.dateTime_cs);
    }
  }

  if (isRunning) {
    if (gpsDataReady && sensorsDataReady) {
      // Check if we pass the finishline (2x2 coordinates for finish line points + 2x2 coordinates for last position + position now)
      if (segIntersect(fix_data.latitude(), fix_data.longitude(), fix_data_prev.latitude(), fix_data_prev.longitude(), flineLat1, flineLon1, flineLat2, flineLon2, posCrossLat, posCrossLon)) {
        addFinishLog = true;
        lapCounter++;
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

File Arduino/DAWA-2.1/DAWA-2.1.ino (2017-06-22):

/*
 * DAWA 2.1
 * Datalogger moto Triumph
 * Edouard PIGEON - 2017
 */

// A commenter ou non si affichage LCD souhaité ou non
#define USE_DISPLAY

// A commenter ou non si utilisation du capteur de position ou non
#define USE_BNO055

// Librairies
#include <SPI.h>
#include <SD.h>
#include <EEPROMAnything.h>
#ifdef USE_DISPLAY
  //#include <SoftwareSerial.h> // /!\ Commenter vecteurs d'interruption dans SoftwareSerial.cpp (Lignes 234 à 244)
  //#include <LiquidCrystal_I2C.h>
  #define I2C_ADDRESS 0x3C
  #include "SSD1306Ascii.h"
  #include "SSD1306AsciiWire.h"
#endif
#ifdef USE_BNO055
  #include <Adafruit_BNO055.h> // Librairies developpées par ADAFRUIT pour capteur 9 axes "USE_BNO055" (https://github.com/adafruit/Adafruit_USE_BNO055)
  #include <Adafruit_Sensor.h>
#endif
#include <DSRTCLib.h>

#ifdef USE_DISPLAY
  //SoftwareSerial mySerial(3,2); // 2x16 SERIAL // Communication avec le LCD sur port série : pin 2 = TX, pin 3 = RX (non utilisé) / FACULTATIF, utilisé à des fins de USE_DISPLAY
  //LiquidCrystal_I2C lcd(0x3F, 16, 2); // 2x16 I2C // Adresse I2C, colonnes, lignes
  SSD1306AsciiWire oled; // OLED I2C
#endif

#ifdef USE_BNO055
  Adafruit_BNO055 bno = Adafruit_BNO055(55, BNO055_ADDRESS_B); // USE_BNO055_ADDRESS_B = Adresse 0x29 (COM3 à 1)
#endif

// Commande LCD si USE_DISPLAY activé ou non
#ifdef USE_DISPLAY
 /*#define LCD_PRINT(x)   mySerial.write(x);
 #define LCD_INIT       mySerial.begin(9600);
 #define LCD_POS(x)     posLCD(x); // 128 = ligne 1, 192 = ligne 2
 #define LCD_CLEAR      clearLCD();;*/
 /*#define LCD_PRINT(x)   lcd.print(x);
 #define LCD_INIT       lcd.begin();
 #define LCD_POS(x,y)   lcd.setCursor(x,y); // colonne,ligne
 #define LCD_CLEAR      lcd.clear();*/
 #define LCD_PRINT(x)   oled.print(x); 
 #define LCD_INIT       oled.begin(&Adafruit128x64, I2C_ADDRESS);oled.setFont(System5x7);
 #define LCD_POS(x,y)   oled.setCursor(x, y);
 #define LCD_CLEAR      oled.clear();    
#else
 #define LCD_PRINT(x);
 #define LCD_INIT;
 #define LCD_POS;
 #define LCD_CLEAR;
#endif

// Variable PINs I/O
const int bno_int_pin = 7; // D7
const int timingPin = 16; // A2
const int rpmPin = 5; // D5
const int ledPin = 4; // D4
const int powerPin = 17; //A3
const int brakePin = 6; //D6
const int throttlePin = 1; // A1
const int gearPin = 0; // A0
const uint8_t chipSelect = 8; // CS : port 8

// Variables programme
uint16_t rpm;
char rpmString[6];
char gearvalueString[6];
bool brake = 0;
bool isRunning = 0;
bool int8hz = 0;
uint8_t runCounter = 0, runCalibration = 0;
uint8_t newRun = 0;
uint16_t throttle;
char throttleString[4];
uint16_t gearValue;
char gear = 'N';
char filename[12];
File dataFile;
char sdString[45];
float sec = 0;
char secString[9];
uint8_t gearNCheck = 0;
uint8_t i, count;
DS1339 RTC = DS1339(0, 0);
uint8_t datetime_array[6]={1,1,17,13,37,0}; // 01/01/17 13:37:00
#ifdef USE_BNO055
  char rollString[5];
  char pitchString[5];
  int8_t temperature;
  char temperatureString[4];
  uint8_t cal_sys, cal_gyro, cal_accel, cal_mag = 0;
  char calString[10];
  adafruit_bno055_offsets_t calibrationData;
  //byte *calibrationBuffer = (byte *) &calibrationData;
#endif
#ifdef USE_DISPLAY
  char datetime[11];
#endif

// Fonction utilisée en cas d'erreur (programme arrêté indéfiniement, led clignote rapidement)
void initerror() {
  delay(2000); // Pause 3 sec pour lecture infos LCD
  while(1) {
    digitalWrite(ledPin, digitalRead(ledPin)^1); // Clignotement LED rapide (indique une erreur)
    delay(100);
  }
}

/*
// Efface les 2 lignes du LCD
void clearLCD() {
  LCD_PRINT(254); // Déplacement curseur ...
  LCD_PRINT(128); // ... première ligne
  LCD_PRINT("                "); // Effacement ligne 1
  LCD_PRINT("                "); // Effacement ligne 2 
}

// Positionne le curseur du LCD sur la position "charPosition"
void posLCD(byte charPosition) {
  LCD_PRINT(254); // Déplacement curseur ...
  LCD_PRINT(charPosition); // Ex : 128 = 1ère ligne, 192 = 2ème ligne
}
*/

// Initialisation
void setup() {
  // Init LCD
  LCD_INIT;
  
  // Init I/O
  pinMode(ledPin, OUTPUT); // Sortie LED de contrôle
  pinMode(powerPin, INPUT); // Bouton ON/OFF
  pinMode(brakePin, INPUT); // Entrée capteur frein
  pinMode(throttlePin, INPUT); // Entrée capteur accélerateur
  pinMode(gearPin, INPUT); // Entrée capteur vitesse engagée
  pinMode(rpmPin, INPUT); // Entrée capteur RPM   
  pinMode(timingPin,INPUT);   // Interruption @8Hz provenant du 1339C+CD4060 (port A2)  
  digitalWrite(timingPin, HIGH);  // Activation résistance tirage
  pinMode(bno_int_pin, INPUT); // Interuption générée par le USE_BNO055 (non utilisé)

  // Init + clear LCD (+Backlight)
  delay(1000); // Temporisation pour démarrage LCD
  LCD_CLEAR;
  
  // Init carte SD
  LCD_POS(0,0);
  LCD_PRINT("SD:");
  if (!SD.begin(chipSelect)) {
    LCD_PRINT("FAILED");
    initerror(); 
  }
  LCD_PRINT("OK");  

  // Init capteur 9 axes
  #ifdef USE_BNO055
    LCD_POS(0,1);
    LCD_PRINT("9AXIS:");
    if(!bno.begin()) {
      LCD_PRINT("FAILED");
      //initerror(); 
    }
    LCD_PRINT("OK");
 
    // Utilisateur d'un quartz externe sur capteur 9 axes
    bno.setExtCrystalUse(true);
  #endif
  
  // Initialisation DS1339C (horloge - librairie DSRTCLib)
  RTC.start();
  RTC.setRegister(DSRTCLib_SP, 0x08); // SQW = 4096Hz (divisé par 1024 avec le CD4060 positionné derrière = 4Hz // Attention interruptions sur fronts montants ET descendants donc 8Hz)
  
  // Initialisation timer1 (comptage RPM) 
  noInterrupts();
  TCCR1A = 0b00000000;  // Doc AMTEL p.131
  TCCR1B = 0b01000111;
  TCNT1 = 0; // Init compteur à 0
  interrupts();

  // Initialisation interruptions sur ports analogiques (A1 à A5)
  *digitalPinToPCMSK(timingPin) |= bit (digitalPinToPCMSKbit(timingPin));  // Activation pin A2 pour interruption toutes les 125ms (8Hz)
  PCIFR  |= bit (digitalPinToPCICRbit(timingPin)); // RAZ flags interuption PCIF1
  PCICR  |= bit (digitalPinToPCICRbit(timingPin)); // Activation interruptions pour PCIE1

  /* 
   * D0-D7 = PCINT 16-23 = PCIR2 = PD = PCIE2 = pcmsk2
   * D8-D13 = PCINT 0-5 = PCIR0 = PB = PCIE0 = pcmsk0
   * A0-A5 (D14-D19) = PCINT 8-13 = PCIR1 = PC = PCIE1 = pcmsk1
   */
  
  #ifdef USE_BNO055
    // Temporisation pour lecture des éventuels codes erreur sur LCD
    digitalWrite(ledPin, HIGH); // On allume la LED pour prevenir la possibilité d'effectuer une calibration
    delay(2000); // Pause 2 sec, le temps à l'utilisateur de demander la calibration si souhaité
    LCD_CLEAR;
  
    // Si l'utilisateur appuie sur le bouton, on démarre la calibration
    if (digitalRead(powerPin) == 1) { 
      // Calibration demandée
      LCD_POS(0,0);
      LCD_PRINT("CALIBRATION ...");
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

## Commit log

2017-03-13 DAWA
    Data Acquisition With Arduino
    [Partslist.xlsx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]
2017-08-16 DAWA v4.0
    DAWA v4.0
    [Partslist.xlsx, Partslist_v4.xlsx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]
2017-08-26 Add laptimer func/bugs
    Add laptimer functionality based on GPS
    Many optimizations (remove temp string vars)
    Bugs correction
    [DAWA-4.0.ino]
2017-09-18 v4.4
    Add comments + bug correction in lap calculations
    [Partslist_v4.4.xlsx]
2018-02-12 DAWA v5.5
    Add analog inputs
    Add HM-10 bluetooth support
    Add connectors
    [dawa_v5.5.GBL, dawa_v5.5.GBO, dawa_v5.5.GBP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]
2018-06-07 DAWA v5.1
    Update DAWA 5.1
    [dawa_v5.1.GBL, dawa_v5.1.GBO, dawa_v5.1.GBP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]
2018-06-10 DAWA v5.1
    [Partslist-v5.1.xlsx]
2018-10-11 3D Case
    STL files for case 3D printing
    [DAWA-CASE v43-down.stl, DAWA-CASE v43-up.stl, MLX v3.stl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]
2020-07-06 STL update
    [DAWA-CASE-PART1.stl, DAWA-CASE-PART2.stl, MLX-PART1.stl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]

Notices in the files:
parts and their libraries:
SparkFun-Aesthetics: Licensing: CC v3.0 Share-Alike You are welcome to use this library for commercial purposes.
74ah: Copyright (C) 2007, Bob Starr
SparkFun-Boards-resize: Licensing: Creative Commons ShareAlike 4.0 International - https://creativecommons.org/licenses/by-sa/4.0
